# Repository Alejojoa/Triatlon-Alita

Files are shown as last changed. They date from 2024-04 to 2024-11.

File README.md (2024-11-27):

# Robot Triatlon - "ALITA" - SPACE ANGELS ROBOTICS
AlitaV2_photo

### Robot de competición desarrollado en el año 2024 por "Space Angels Robotics", con el objetivo de participar de los Juegos Bonaerenses del correspondiente año en la categoría de "Triatlón Robótico".
Campéon Regional en la categoría de "Triatlón Robótico" en la Universidad de Quilmes el (22 Ago).
Participación en los Juegos Bonaerenses 2024 (28 Oct. - 2 Nov.)

Llevado a cabo por alumnos de 6to año de la Técnica n°5 "2 de Abril" en la carrera de Electrónica.
Alita es un robot diseñado para fines plenamente educativos, contado con múltiples versiones, con el objetivo de superarse a si misma en cada una de sus etapas.

Todo el proyecto ha sido realizado en Vistual Studio Code con la extensión de PlarformIO en lenguaje C++ Orientado a Objetos.
Diseño de PCBs realizado en KiCad 8.0
Diseño de Hardware3D en Fusion 360

Participantes: Guerra Alejo Joaqín
               Lazzatti Lucas
               Regidor Jeremías
               Romano Iván
               Rossi Mamberti Valentina Jenifer

Director Técnico: Prof. Barzola Maximiliano Andrés

 Este robót cuenta con diferentes categorías, de las cuales cada una tendrá su rama individual con su última versión vigente.

 ## despeja_area
 Rama dedicada a la programación final (Alita V3) en la categoría de "Despeja Area" (Autonomo). Su objetivo será el de quitar de la pista una serie de cubos de la forma más rápida y eficiente posible, sin salir de la pista. 

   -.vscode
        Archivos generados por el IDE Visual Studio Code y la extensión de PlatformIO.
        
   -fimware
        Código actual individual de despeja_area.

 ## sprinter
 Rama dedicada a la programación final (Alita V3) en la categoría de "Velocista" (Autonomo). Su objetivo será el de completar una pista en su totalidad de la forma más rápida posible, pudiendo de igual forma incluir obstáculos o no.

   -.vscode
        Archivos generados por el IDE Visual Studio Code y la extensión de PlatformIO.
        
   -fimware
        Código actual individual de sprinter.

 ## sumo
 Rama dedicada a la programación final (Alita V3) en la categoría de "Sumo RC" (Radio Controlado). Su objertivo será el de quitar del tatami al rival, siendo un operario el encargado de manejar el robot. 

   -.vscode
        Archivos generados por el IDE Visual Studio Code y la extensión de PlatformIO.

   -fimware
        Código actual indiviual de sumo.

 ## menu
 Alita, en todas sus versiónes, incluye un menu comandado por pulsadores incluidos en el lateral izquierdo de robot para mayor comodidad del usuario. En esta rama encontrará la programación dedicada al manejo de esta interfaz. 

  -.vscode
       Archivos generados por el IDE Visual Studio Code y la extensión de PlatformIO.

  -fimware
       Programación de la interfaz de menú.

 ## main
 Esta es la rama principal del repositorio. En ella se encontrará la union de todas las ramas en una sola junto al hardware de Alita.

   -.vscode
        Archivos generados por el IDE Vistual Studio Code y la extensión de PlatformIO.

   -fimware
        Unión de las ramas individuales en una sola para mayor comodidad, dandole así a la interfaz del menu.

   -hardware
        PCBs empleadas en el robot, tanto como principales como drivers y multiplexores.

   -hardware 3D
        Diseños 3D de las diferentes versiones de Alita.

 ## stage
 Rama de pruebas de uniones previas a la rama main.

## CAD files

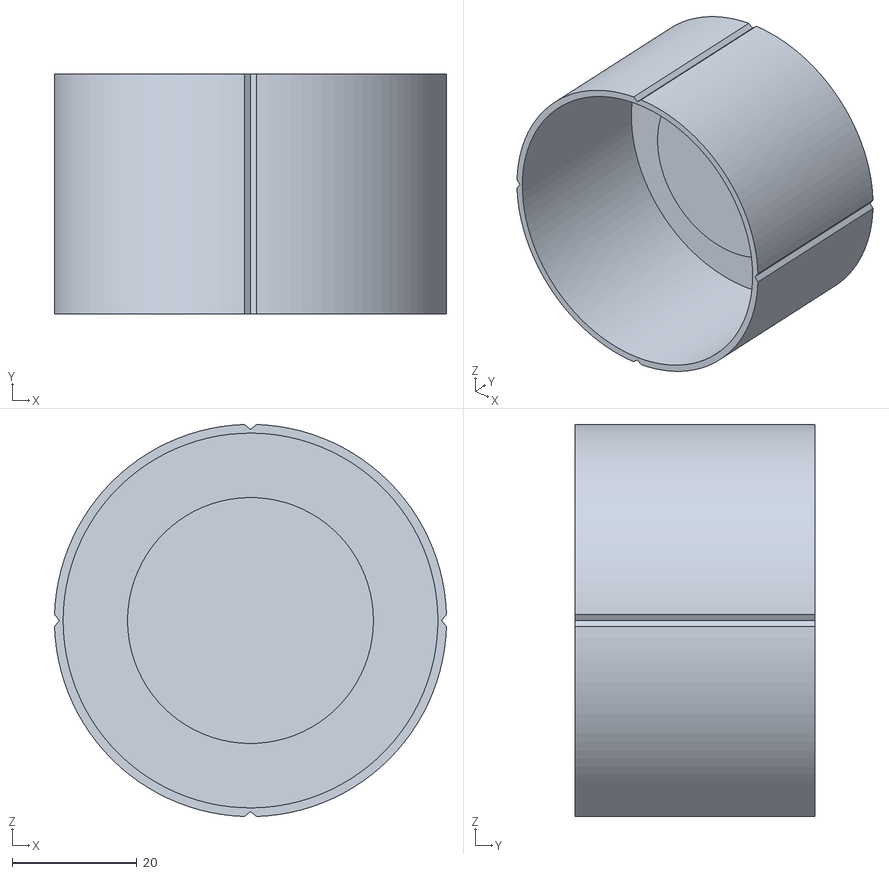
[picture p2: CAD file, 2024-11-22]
Hardware 3D/AlitaV3/RuedaTitanMolde60MM.stl
63.0 x 38.5 x 63.0

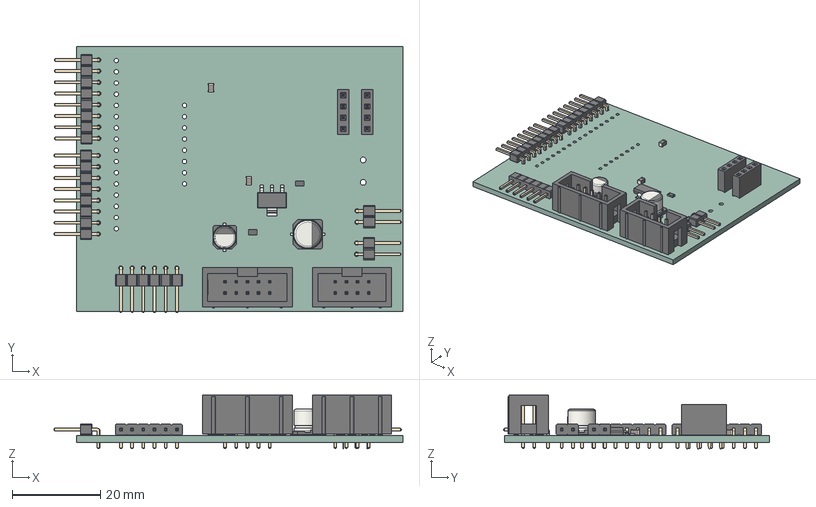
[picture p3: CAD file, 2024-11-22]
Hardware/PCBTriatlonNueva/PCBTriatlonNueva.step
79.1 x 60.2 x 12.2 mm
IDC_Header_2x05_P254mm_Vertical
CP_Elec_63x59
CP_Elec_5x45
SOT_223
R_0805_2012Metric x 2
PinSocket_1x04_P254mm_Vertical x 2
PinHeader_1x08_P254mm_Horizontal x 2
PinHeader_1x06_P254mm_Horizontal
C_0805_2012Metric x 2
PinHeader_1x02_P254mm_Horizontal x 2
IDC_Header_2x04_P254mm_Vertical
PCBTriatlonNueva_PCB

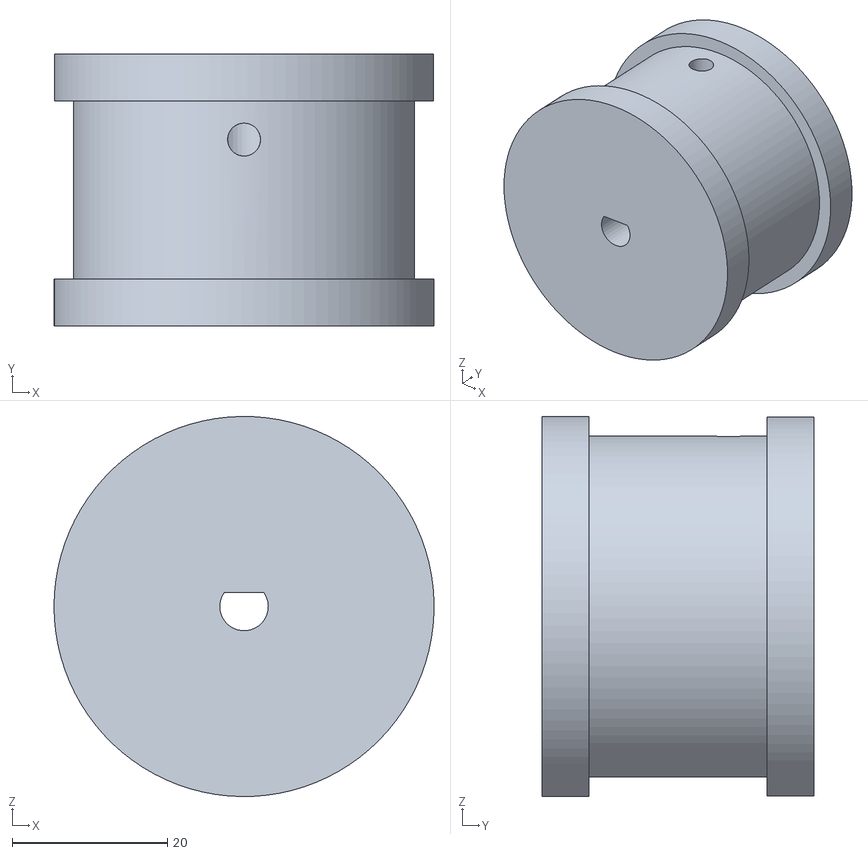
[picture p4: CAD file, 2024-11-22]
Hardware 3D/AlitaV3/Rueda60MM Mod.stl
49.0 x 35.0 x 49.0

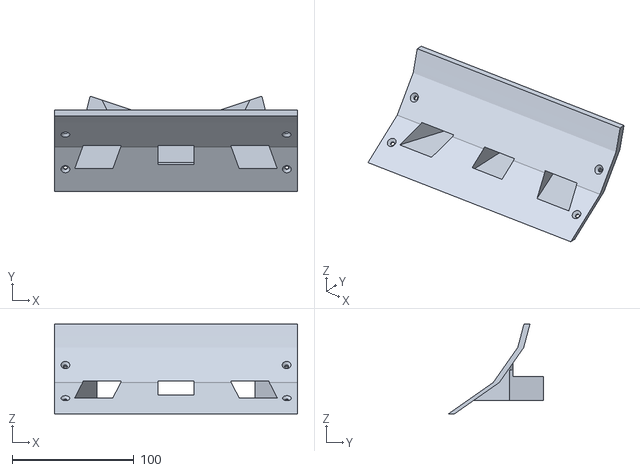
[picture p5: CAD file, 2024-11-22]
Hardware 3D/AlitaV3/Frente del chasis.stl
200.0 x 78.3 x 73.9

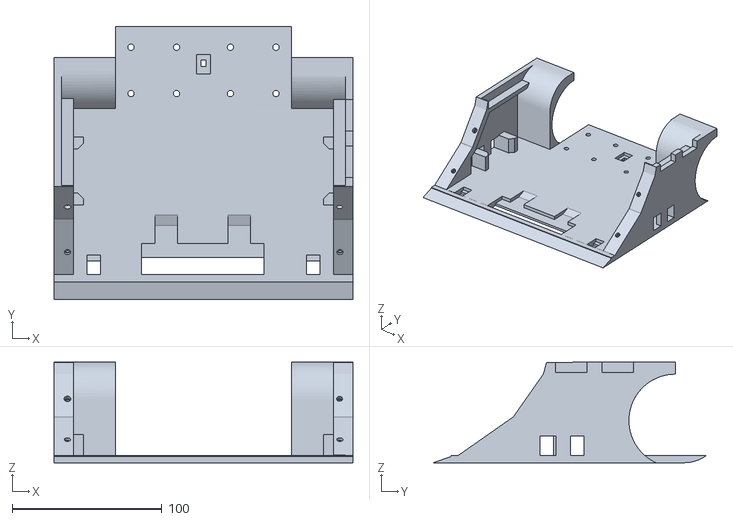
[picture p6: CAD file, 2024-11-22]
Hardware 3D/AlitaV3/ChasisV3.stl
200.0 x 182.9 x 67.3

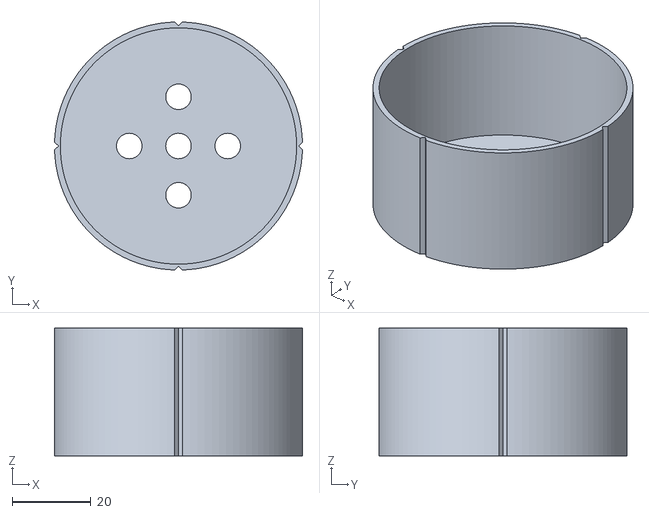
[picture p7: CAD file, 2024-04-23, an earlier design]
Hardware 3D/AlitaV1/MoldeRueda60MM.stl
63.0 x 63.0 x 32.5

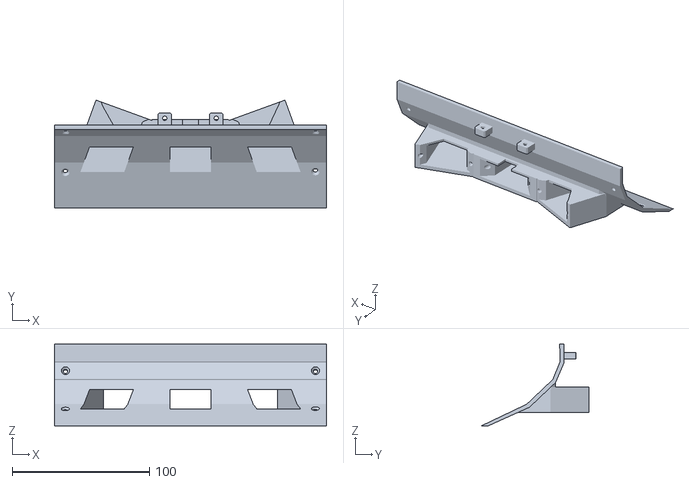
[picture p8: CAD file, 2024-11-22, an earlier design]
Hardware 3D/AlitaV2.1/FrenteAlitaV2.stl
198.0 x 78.5 x 59.7

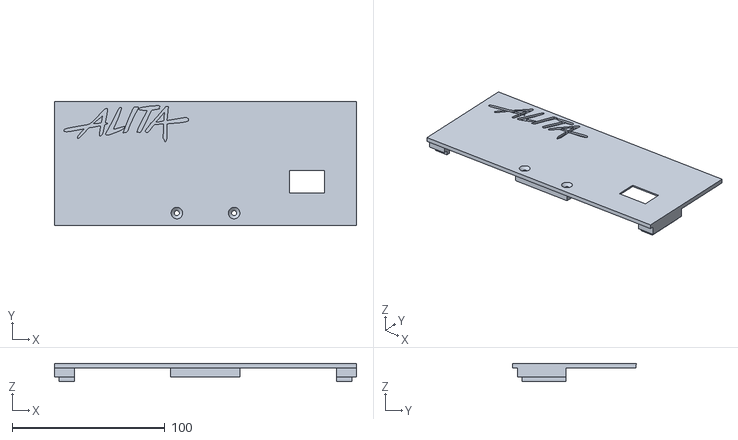
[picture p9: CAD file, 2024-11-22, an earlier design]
Hardware 3D/AlitaV2.1/Old/TapaAlitaV2.stl
198.0 x 81.0 x 12.0

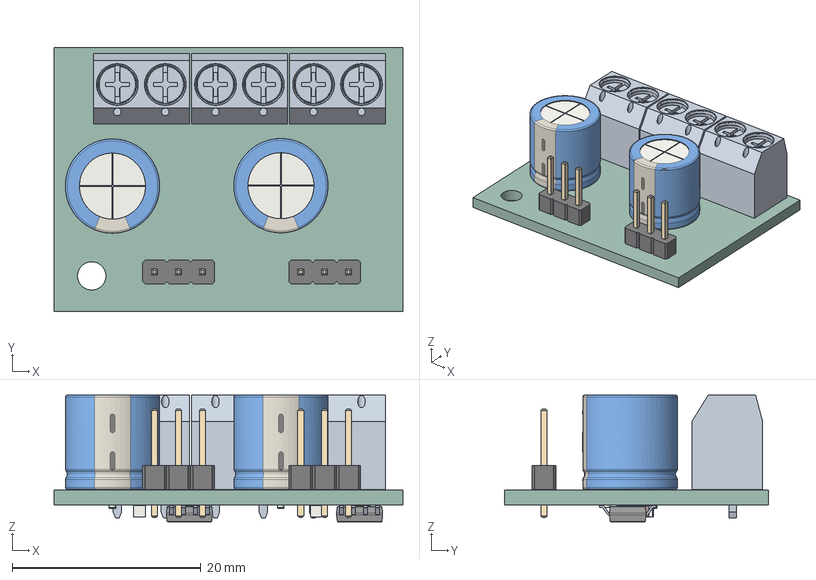
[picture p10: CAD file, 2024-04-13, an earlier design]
Hardware/old_DriverMotoresx2TB67H450FNG/DriverMotoresx2TB67H450FNG.step
37.0 x 28.0 x 13.5 mm
PinHeader_1x03_P254mm_Vertical x 2
ASSEMBLY x 5
CP_Radial_D100mm_P500mm x 2
C_0805_2012Metric x 2
DriverMotoresx2TB67H450FNG_PCB

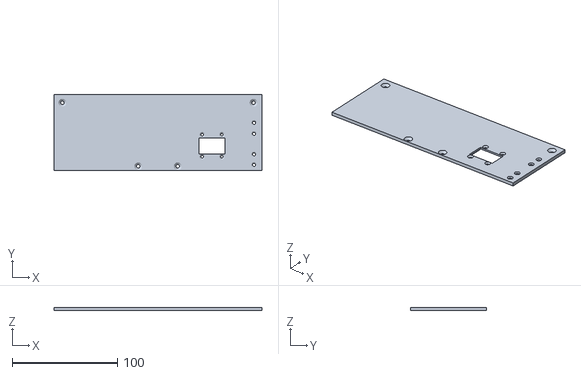
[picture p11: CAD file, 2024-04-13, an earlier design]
Hardware 3D/AlitaV1/Tapa robot.stl
198.0 x 72.6 x 3.00

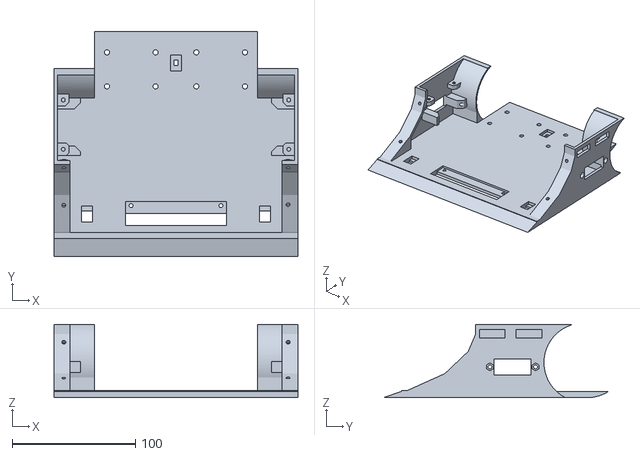
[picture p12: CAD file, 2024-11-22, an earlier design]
Hardware 3D/AlitaV2.1/Old/ChasisAlitaV2.stl
198.0 x 182.4 x 59.5

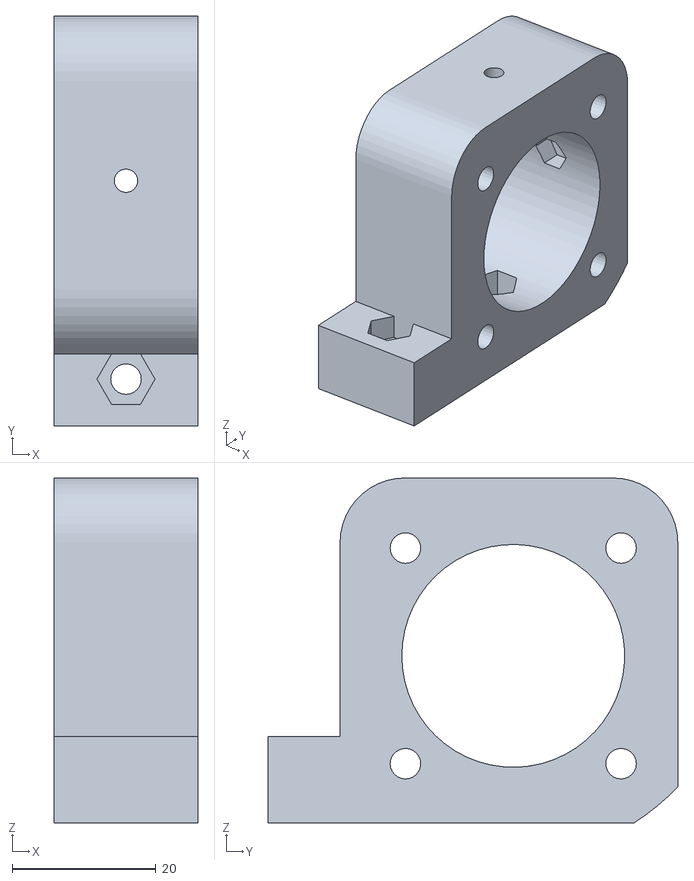
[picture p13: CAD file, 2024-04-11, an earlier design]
Hardware 3D/AlitaV1/SoporteIzquierdo.stl
20.0 x 57.0 x 48.0

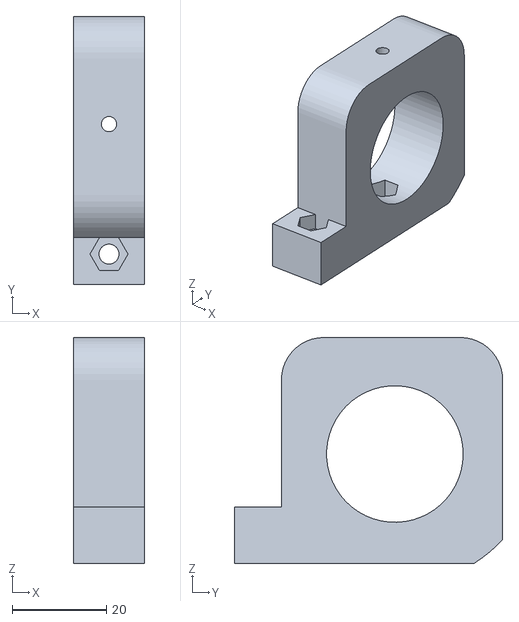
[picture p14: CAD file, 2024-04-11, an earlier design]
Hardware 3D/AlitaV1/SoporteCentral.stl
15.0 x 57.0 x 48.0

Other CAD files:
Hardware 3D/AlitaV2.1/Tapa PantallaOled1.3.stl
Hardware 3D/AlitaV1/SoporteDerecho.stl
Hardware 3D/AlitaV2.1/SoporteDerecho.stl
Hardware 3D/AlitaV1/Chasis principal.stl

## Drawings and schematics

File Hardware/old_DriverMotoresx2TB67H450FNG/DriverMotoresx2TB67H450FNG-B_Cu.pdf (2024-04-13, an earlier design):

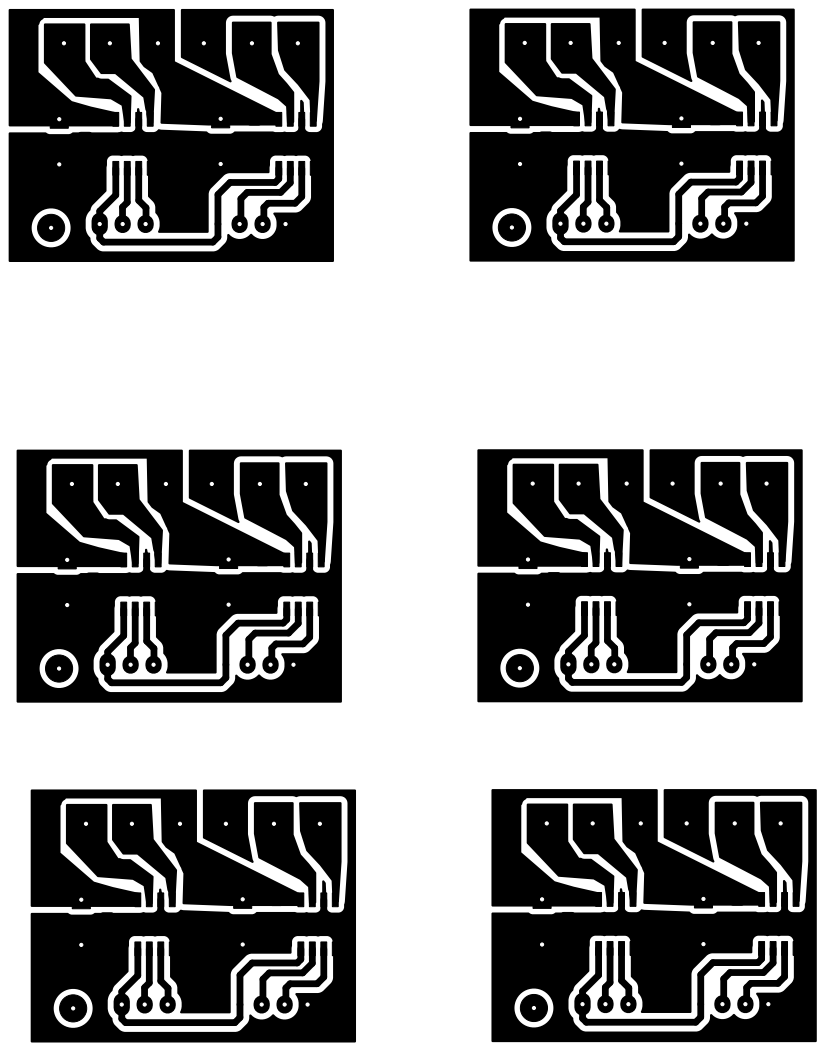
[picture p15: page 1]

Id: 1/1 Title: File: DriverMotoresx2TB67H450FNG.kicad_pcb Sheet:

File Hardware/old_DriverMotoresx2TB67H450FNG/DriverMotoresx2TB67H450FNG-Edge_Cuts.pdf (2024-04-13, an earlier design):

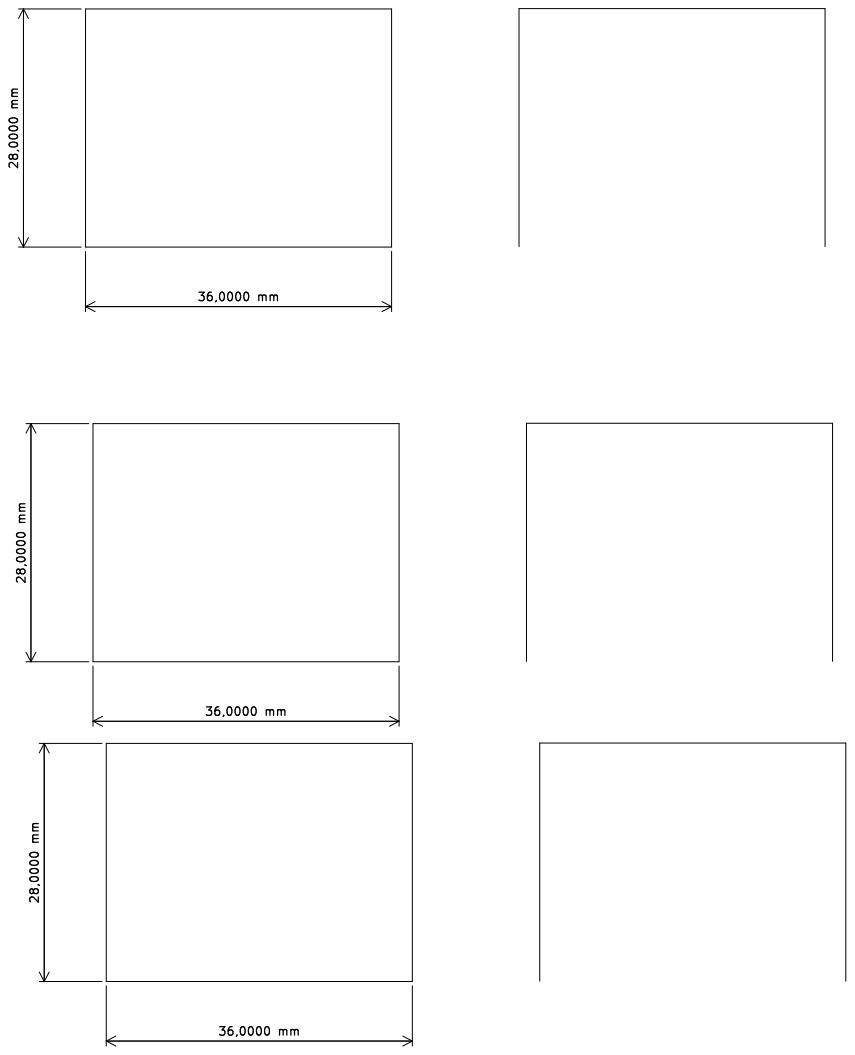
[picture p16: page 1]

Id: 1/1 Title: File: DriverMotoresx2TB67H450FNG.kicad_pcb Sheet: 28,0000 mm

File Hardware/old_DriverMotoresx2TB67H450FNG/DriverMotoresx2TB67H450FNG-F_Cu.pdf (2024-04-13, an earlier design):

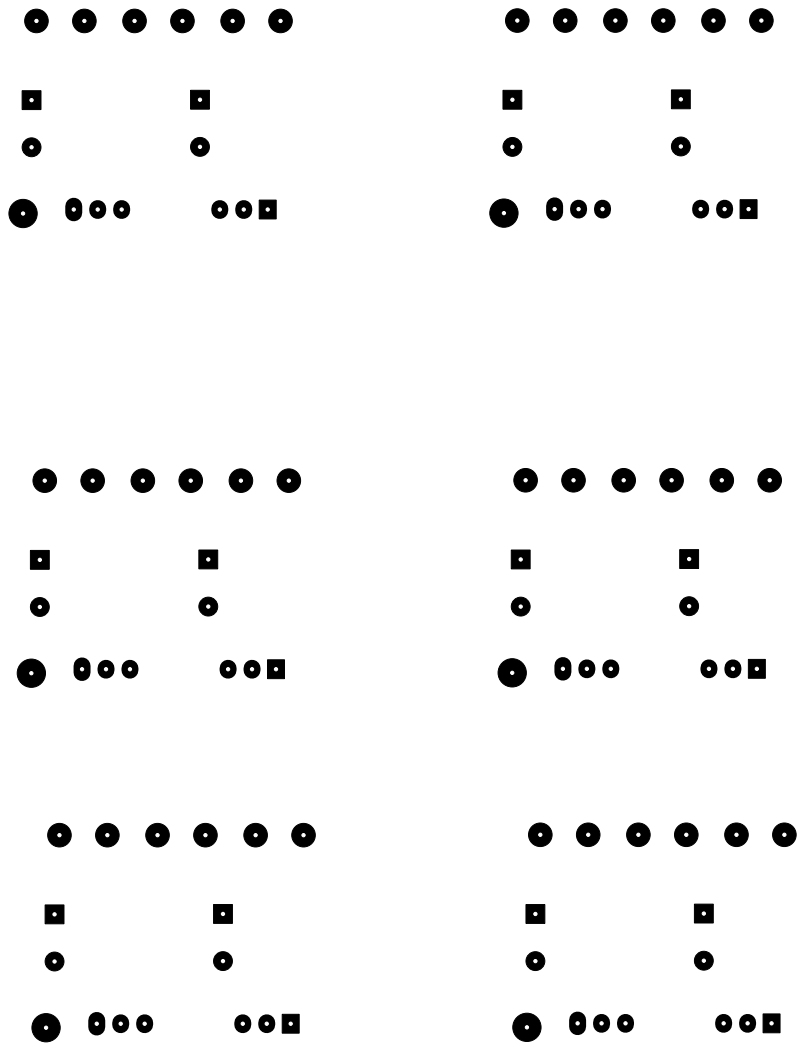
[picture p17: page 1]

Id: 1/1 Title: File: DriverMotoresx2TB67H450FNG.kicad_pcb Sheet:

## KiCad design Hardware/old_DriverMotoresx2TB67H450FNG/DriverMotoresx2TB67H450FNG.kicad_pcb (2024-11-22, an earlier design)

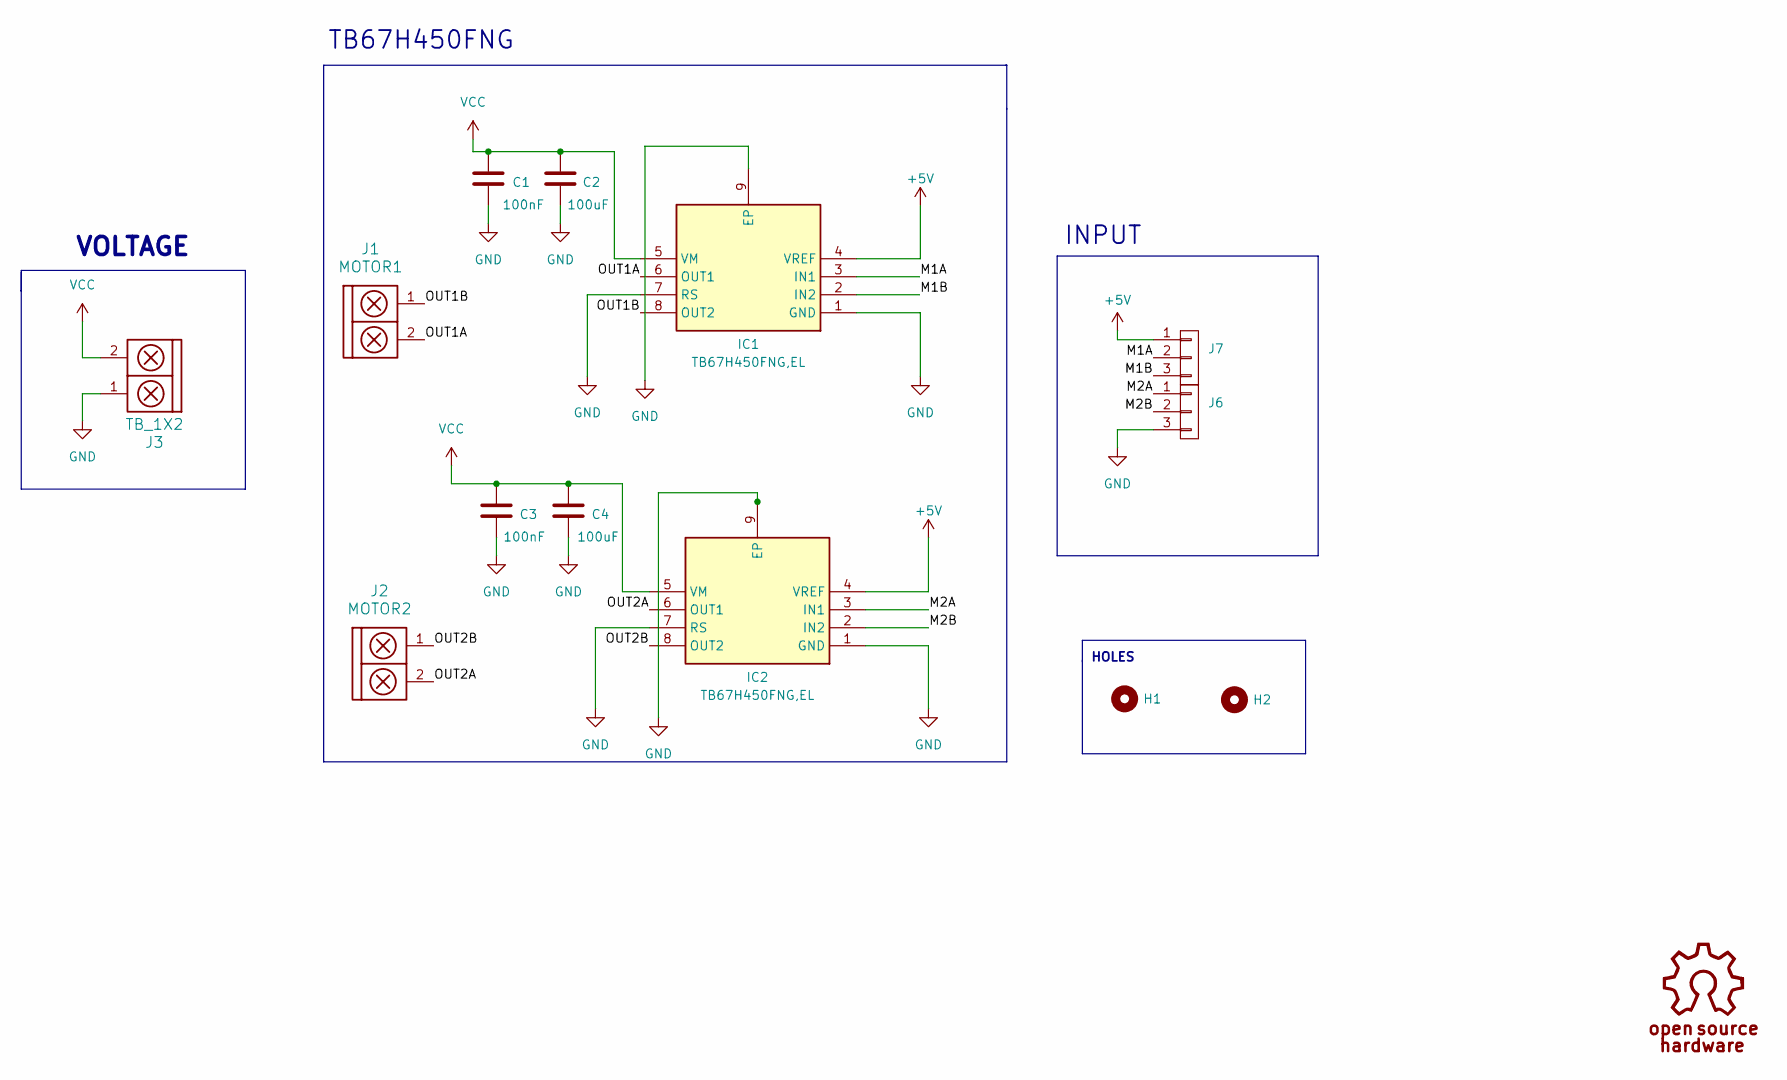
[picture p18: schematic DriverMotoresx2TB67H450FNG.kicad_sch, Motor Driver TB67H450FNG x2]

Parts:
C1, C3: 100nF; C_0805_2012Metric_Pad1.18x1.45mm_HandSolder
C2, C4: 100uF; CP_Radial_D10.0mm_P5.00mm
H1, H2: Mounting_Hole; hole_3mm
IC1, IC2: TB67H450FNG,EL; SOIC127P600X170-9N; Mouser Part Number 757-TB67H450FNGEL
J1: MOTOR1; BORNERA2_AZUL
J2: MOTOR2; BORNERA2_AZUL
J3: TB_1X2; BORNERA2_AZUL
J6, J7: Conn_01X03; PinHeader_1x03_P2.54mm_Vertical

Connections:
+5V: IC1.4 (VREF), IC2.4 (VREF), J7.1
/M1A: IC1.3 (IN1), J7.2
/M1B: IC1.2 (IN2), J7.3
/M2A: IC2.3 (IN1), J6.1
/M2B: IC2.2 (IN2), J6.2
/OUT1A: IC1.6 (OUT1), J1.2
/OUT1B: IC1.8 (OUT2), J1.1
/OUT2A: IC2.6 (OUT1), J2.2
/OUT2B: IC2.8 (OUT2), J2.1
GND: C1.2, C2.2, C3.2, C4.2, IC1.1 (GND), IC1.7 (RS), IC1.9 (EP), IC2.1 (GND), IC2.7 (RS), IC2.9 (EP), J3.1, J6.3
VCC: C1.1, C2.1, C3.1, C4.1, IC1.5 (VM), IC2.5 (VM), J3.2

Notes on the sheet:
HOLES
INPUT
TB67H450FNG
VOLTAGE

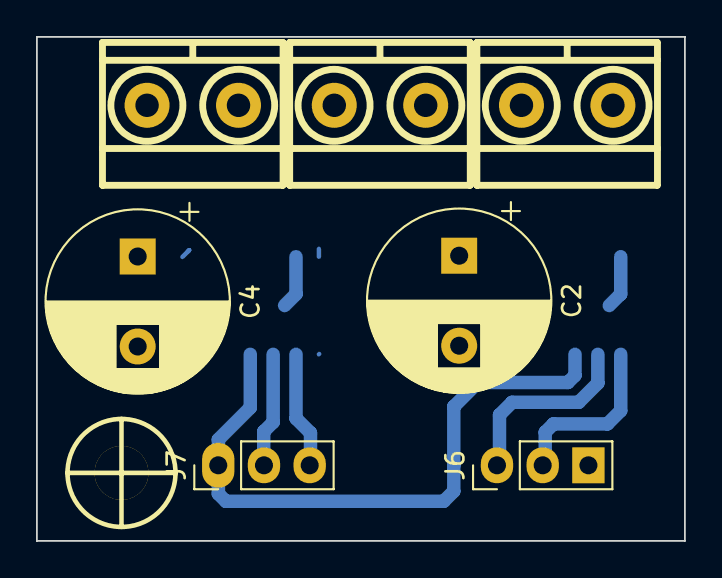
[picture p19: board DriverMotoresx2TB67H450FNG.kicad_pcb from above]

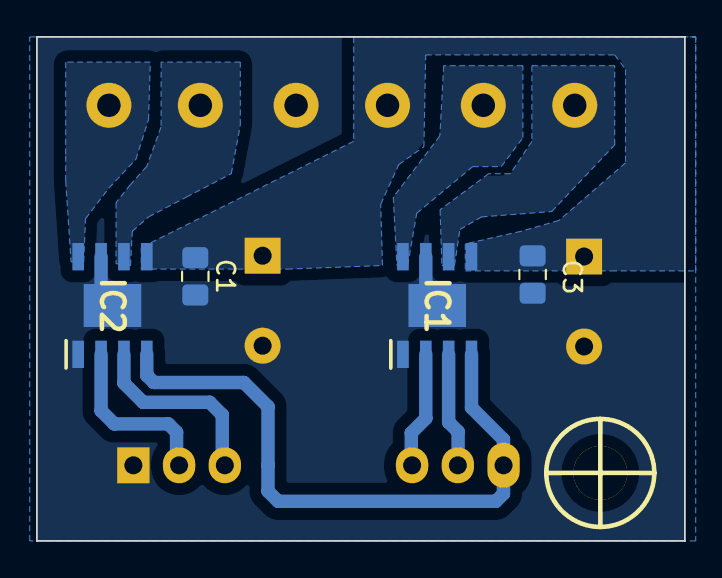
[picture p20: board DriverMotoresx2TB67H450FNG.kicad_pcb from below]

Board: 2 copper layers, 36.0 x 28.0 mm, 12 parts (4 on the bottom side), 11 nets.

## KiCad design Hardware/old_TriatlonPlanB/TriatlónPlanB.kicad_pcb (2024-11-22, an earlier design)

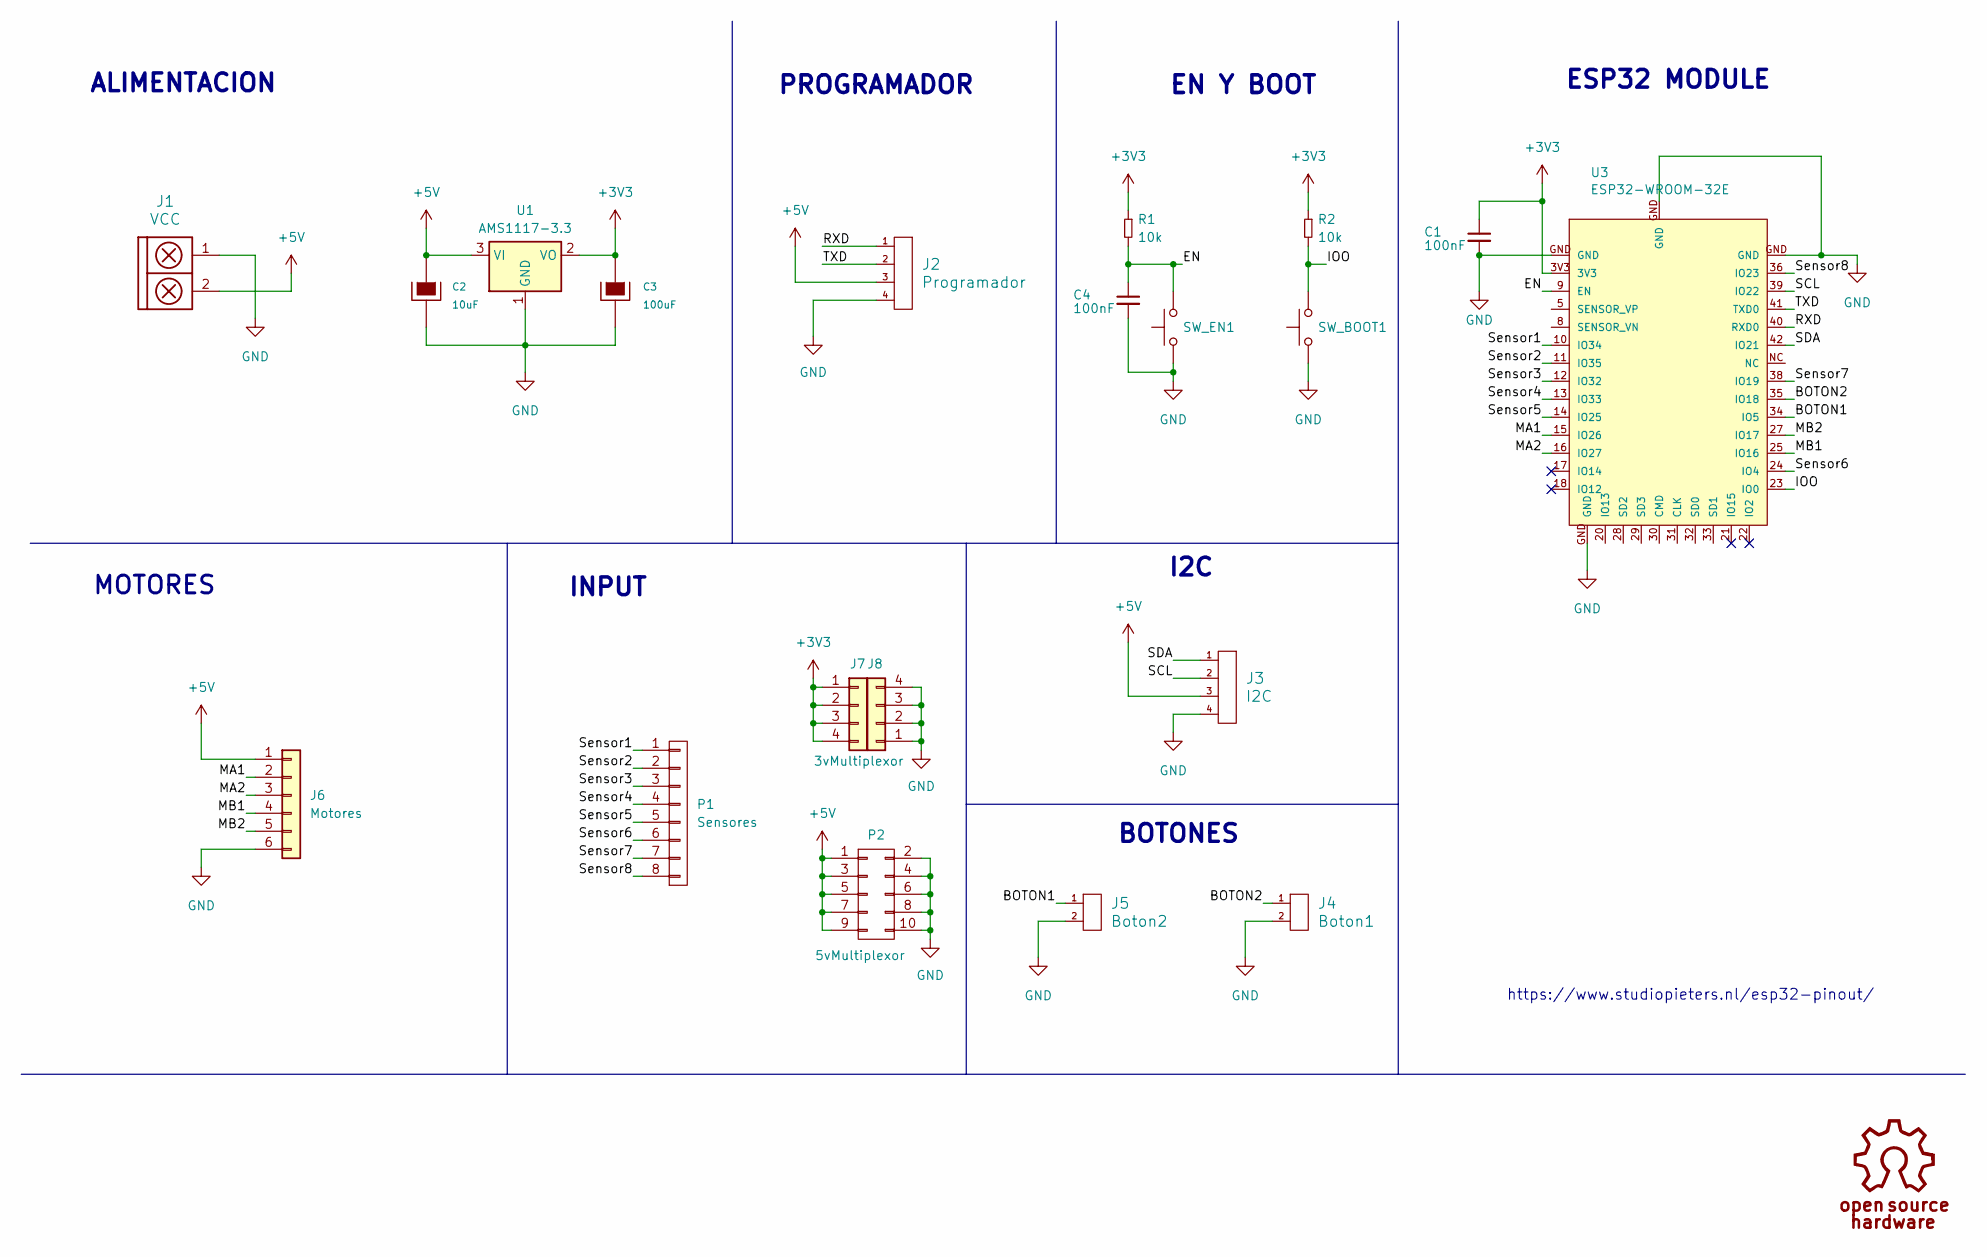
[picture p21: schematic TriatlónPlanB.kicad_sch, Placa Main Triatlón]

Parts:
C1, C4: 100nF; C_0805
C2: 10uF; CP_Elec_5x4.5
C3: 100uF; CP_Elec_6.3x5.9
J1: VCC; BORNERA2_AZUL
J2: Programador; PinSocket_1x04_P2.54mm_Vertical
J3: I2C; PinSocket_1x04_P2.54mm_Vertical
J4: Boton1; PinHeader_1x02_P2.54mm_Vertical
J5: Boton2; PinHeader_1x02_P2.54mm_Vertical
J6: Motores; Pin_Header_6
J7, J8: 3vMultiplexor; pin_strip_4
P1: Sensores; PinSocket_1x08_P2.54mm_Vertical
P2: 5vMultiplexor; Pin_Header_02x05
R1, R2: 10k; R_0805_2012Metric
SW_BOOT1: SW_Push; Pulsador_SMD_2_ALTO
SW_EN1: SW_Push; Pulsador_SMD_2_ALTO
U1: AMS1117-3.3; SOT-223-3_TabPin2
U3: ESP32-WROOM-32E

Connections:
+3V3: C1.1, C3.1, J7.1, J7.2, J7.3, J7.4, R1.1, R2.1, U1.2 (VO), U3.3V3
+5V: C2.1, J1.2, J2.3, J3.3, J6.1, P2.1, P2.3, P2.5, P2.7, P2.9, U1.3 (VI)
/BOTON1: J5.1, U3.34 (IO5)
/BOTON2: J4.1, U3.35 (IO18)
/EN: C4.1, R1.2, SW_EN1.2, U3.9 (EN)
/IOO: R2.2, SW_BOOT1.2, U3.23 (IO0)
/MA1: J6.2, U3.15 (IO26)
/MA2: J6.3, U3.16 (IO27)
/MB1: J6.4, U3.25 (IO16)
/MB2: J6.5, U3.27 (IO17)
/RXD: J2.1, U3.40 (RXD0)
/SCL: J3.2, U3.39 (IO22)
/SDA: J3.1, U3.42 (IO21)
/Sensor1: P1.1, U3.10 (IO34)
/Sensor2: P1.2, U3.11 (IO35)
/Sensor3: P1.3, U3.12 (IO32)
/Sensor4: P1.4, U3.13 (IO33)
/Sensor5: P1.5, U3.14 (IO25)
/Sensor7: P1.7, U3.38 (IO19)
/Sensor8: P1.8, U3.36 (IO23)
/TXD: J2.2, U3.41 (TXD0)
GND: C1.2, C2.2, C3.2, C4.2, J1.1, J2.4, J3.4, J4.2, J5.2, J6.6, J8.1, J8.2, J8.3, J8.4, P2.2, P2.4, P2.6, P2.8, P2.10, SW_BOOT1.1, SW_EN1.1, U1.1 (GND), U3.GND

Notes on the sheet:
INPUT
BOTONES
ALIMENTACION
I2C
EN Y BOOT
ESP32 MODULE
PROGRAMADOR
https://www.studiopieters.nl/esp32-pinout/
MOTORES

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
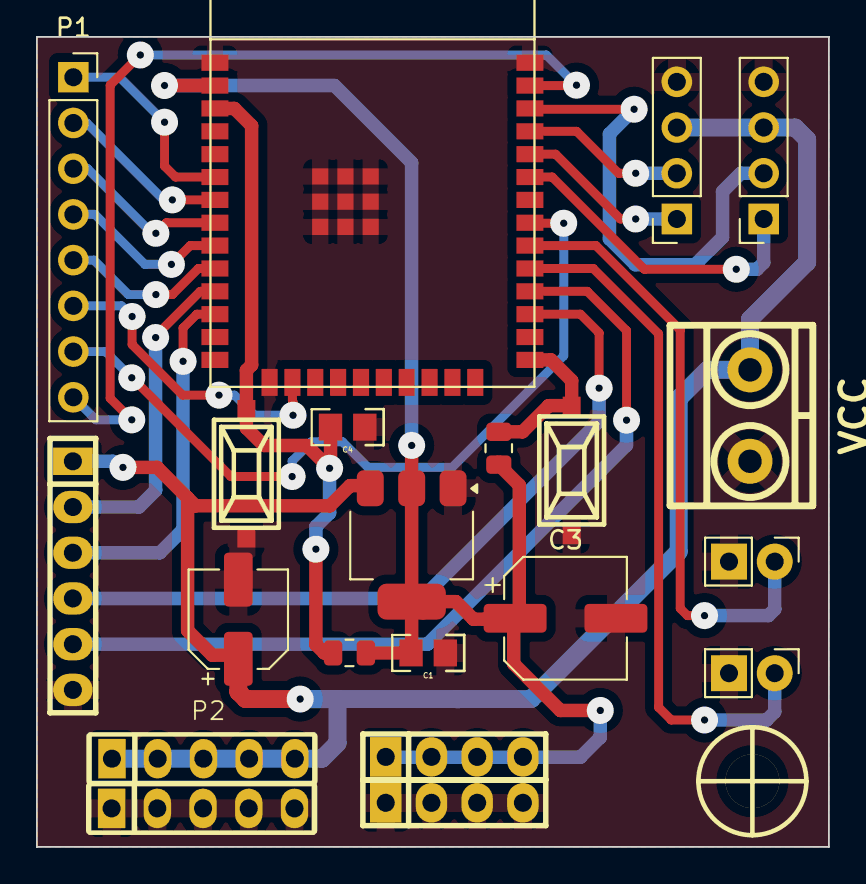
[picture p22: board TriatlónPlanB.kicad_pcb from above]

Board: 2 copper layers, 44.0 x 45.0 mm, 21 parts (0 on the bottom side), 23 nets.

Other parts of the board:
hole_3mm: VAL**; hole_3mm

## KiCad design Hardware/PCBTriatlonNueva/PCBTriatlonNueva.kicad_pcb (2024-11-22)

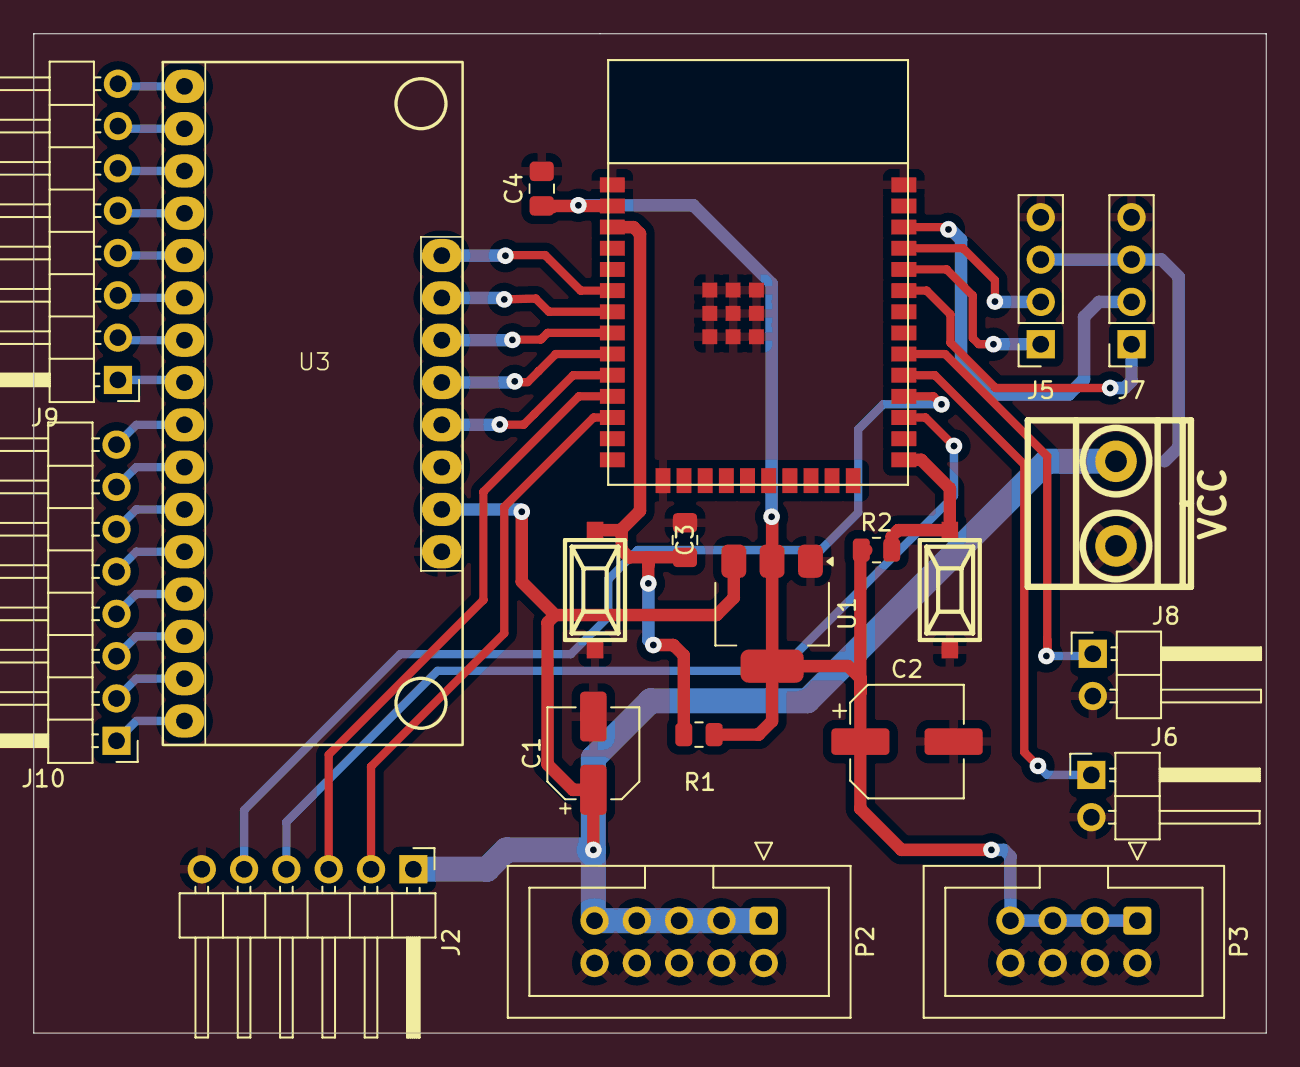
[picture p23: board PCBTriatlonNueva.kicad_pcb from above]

Board: 2 copper layers, 74.0 x 60.0 mm, 21 parts (0 on the bottom side), 36 nets.

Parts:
C1: 10uF; CP_Elec_5x4.5
C2: 100uF; CP_Elec_6.3x5.9
C3, C4: 100nF; C_0805_2012Metric_Pad1.18x1.45mm_HandSolder
J1: VCC; BORNERA2
J2: Motores; PinHeader_1x06_P2.54mm_Horizontal
J5: Programador; PinSocket_1x04_P2.54mm_Vertical
J6: Boton2; PinHeader_1x02_P2.54mm_Horizontal
J7: I2C; PinSocket_1x04_P2.54mm_Vertical
J8: Boton1; PinHeader_1x02_P2.54mm_Horizontal
J9: MUX_header1; PinHeader_1x08_P2.54mm_Horizontal
J10: MUX_header2; PinHeader_1x08_P2.54mm_Horizontal
P2: 5vMultiplexor; IDC-Header_2x05_P2.54mm_Vertical
P3: 5vMultiplexor; IDC-Header_2x04_P2.54mm_Vertical
R1, R2: 10k; R_0805_2012Metric
SW_BOOT1: SW_Push; Pulsador_SMD_2_ALTO
SW_EN1: SW_Push; Pulsador_SMD_2_ALTO
U1: AMS1117-3.3; SOT-223-3_TabPin2
U2: ESP32-WROOM-32E
U3: MUX 4067; HP4067_module

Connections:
+3V3: C2.1, C4.1, P3.1, P3.3, P3.5, P3.7, R1.1, R2.1, U1.2 (VO), U2.3V3
+5V: C1.1, J1.2, J2.1, J5.3, J7.3, P2.1, P2.3, P2.5, P2.7, P2.9, U1.3 (VI), U3.23 (VCC)
/BOTON1: J6.1, U2.34 (IO5)
/BOTON2: J8.1, U2.35 (IO18)
/EN: C3.1, R1.2, SW_EN1.2, U2.9 (EN)
/IOO: R2.2, SW_BOOT1.2, U2.23 (IO0)
/MA1: J2.3, U2.15 (IO26)
/MA2: J2.2, U2.16 (IO27)
/MB1: J2.4, U2.25 (IO16)
/MB2: J2.5, U2.27 (IO17)
/MULTIPLEXOR1: U2.14 (IO25), U3.21 (S0)
/MULTIPLEXOR2: U2.13 (IO33), U3.20 (S1)
/MULTIPLEXOR3: U2.12 (IO32), U3.19 (S2)
/MULTIPLEXOR4: U2.11 (IO35), U3.18 (S3)
/MULTIPLEXOR5: U2.10 (IO34), U3.17 (SIG)
/RXD: J5.1, U2.40 (RXD0)
/SCL: J7.2, U2.39 (IO22)
/SDA: J7.1, U2.42 (IO21)
/TXD: J5.2, U2.41 (TXD0)
GND: C1.2, C2.2, C3.2, C4.2, J1.1, J2.6, J5.4, J6.2, J7.4, J8.2, P2.2, P2.4, P2.6, P2.8, P2.10, P3.2, P3.4, P3.6, P3.8, SW_BOOT1.1, SW_EN1.1, U1.1 (GND), U2.GND, U3.24 (GND)
unnamed: J9.1, U3.8 (C8)
unnamed: J9.2, U3.7 (C9)
unnamed: J9.3, U3.6 (C10)
unnamed: J9.4, U3.5 (C11)
unnamed: J9.5, U3.4 (C12)
unnamed: J9.6, U3.3 (C13)
unnamed: J9.7, U3.2 (C14)
unnamed: J9.8, U3.1 (C15)
unnamed: J10.1, U3.16 (C0)
unnamed: J10.2, U3.15 (C1)
unnamed: J10.3, U3.14 (C2)
unnamed: J10.4, U3.13 (C3)
unnamed: J10.5, U3.12 (C4)
unnamed: J10.6, U3.11 (C5)
unnamed: J10.7, U3.10 (C6)
unnamed: J10.8, U3.9 (C7)

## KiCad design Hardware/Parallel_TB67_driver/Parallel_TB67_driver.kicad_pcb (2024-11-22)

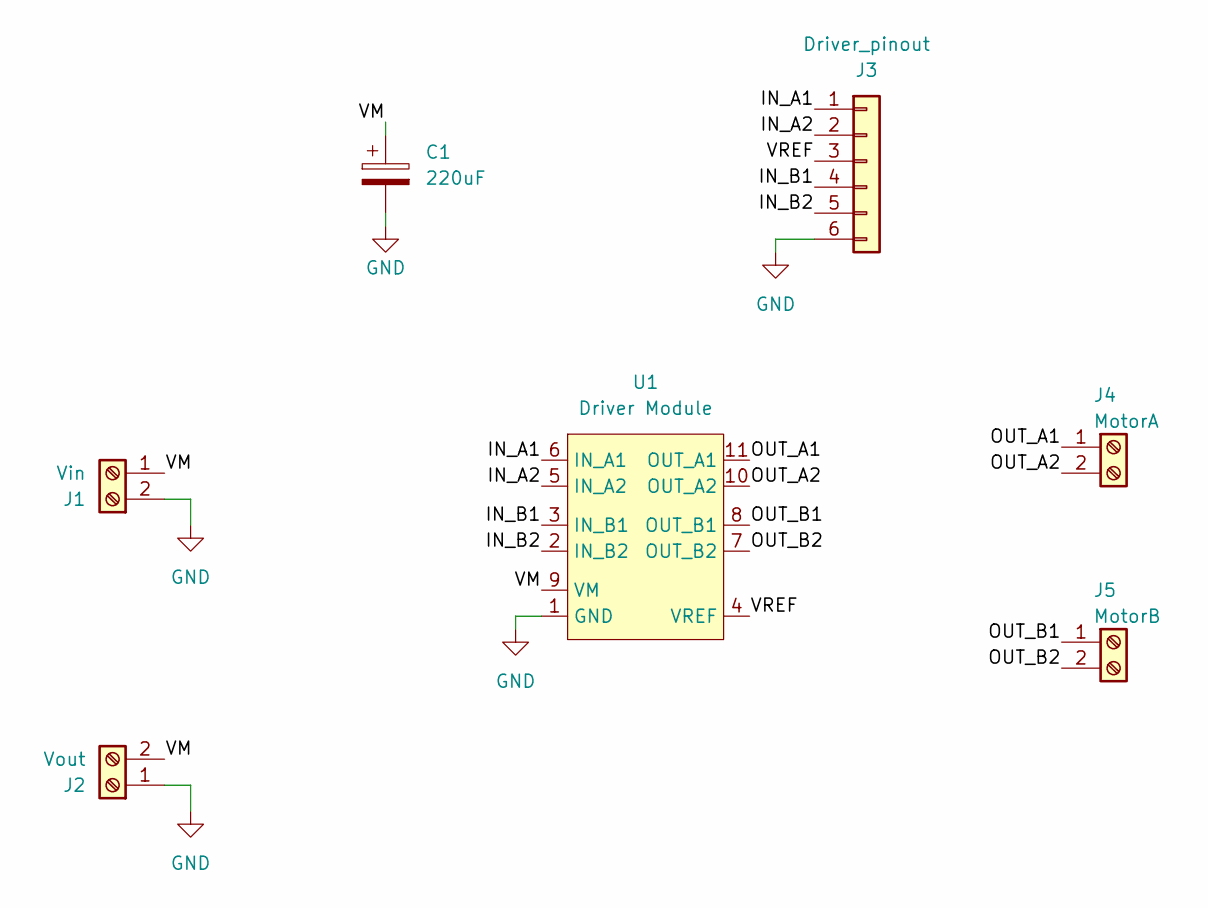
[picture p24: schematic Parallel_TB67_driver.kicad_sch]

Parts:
C1: 220uF; CP_Radial_D10.0mm_P3.50mm
J1: Vin; BORNERA2_AZUL
J2: Vout; BORNERA2_AZUL
J3: Driver_pinout; Molex_KK-254_AE-6410-06A_1x06_P2.54mm_Vertical
J4: MotorA; BORNERA2_AZUL
J5: MotorB; BORNERA2_AZUL
U1: Driver Module; Dual-Driver-Module

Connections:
/IN_A1: J3.1, U1.6 (IN_A1)
/IN_A2: J3.2, U1.5 (IN_A2)
/IN_B1: J3.4, U1.3 (IN_B1)
/IN_B2: J3.5, U1.2 (IN_B2)
/OUT_A1: J4.1, U1.11 (OUT_A1)
/OUT_A2: J4.2, U1.10 (OUT_A2)
/OUT_B1: J5.1, U1.8 (OUT_B1)
/OUT_B2: J5.2, U1.7 (OUT_B2)
/VM: C1.1, J1.1 (Pin_2), J2.2, U1.9 (VM)
/VREF: J3.3, U1.4 (VREF)
GND: C1.2, J1.2 (Pin_1), J2.1, J3.6, U1.1 (GND)

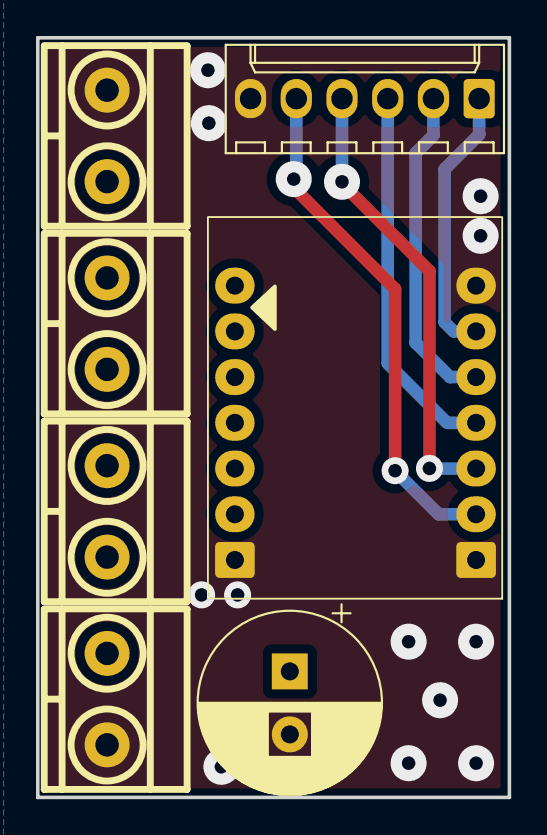
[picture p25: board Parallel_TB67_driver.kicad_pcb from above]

Board: 2 copper layers, 26.2 x 42.2 mm, 7 parts (0 on the bottom side), 11 nets.

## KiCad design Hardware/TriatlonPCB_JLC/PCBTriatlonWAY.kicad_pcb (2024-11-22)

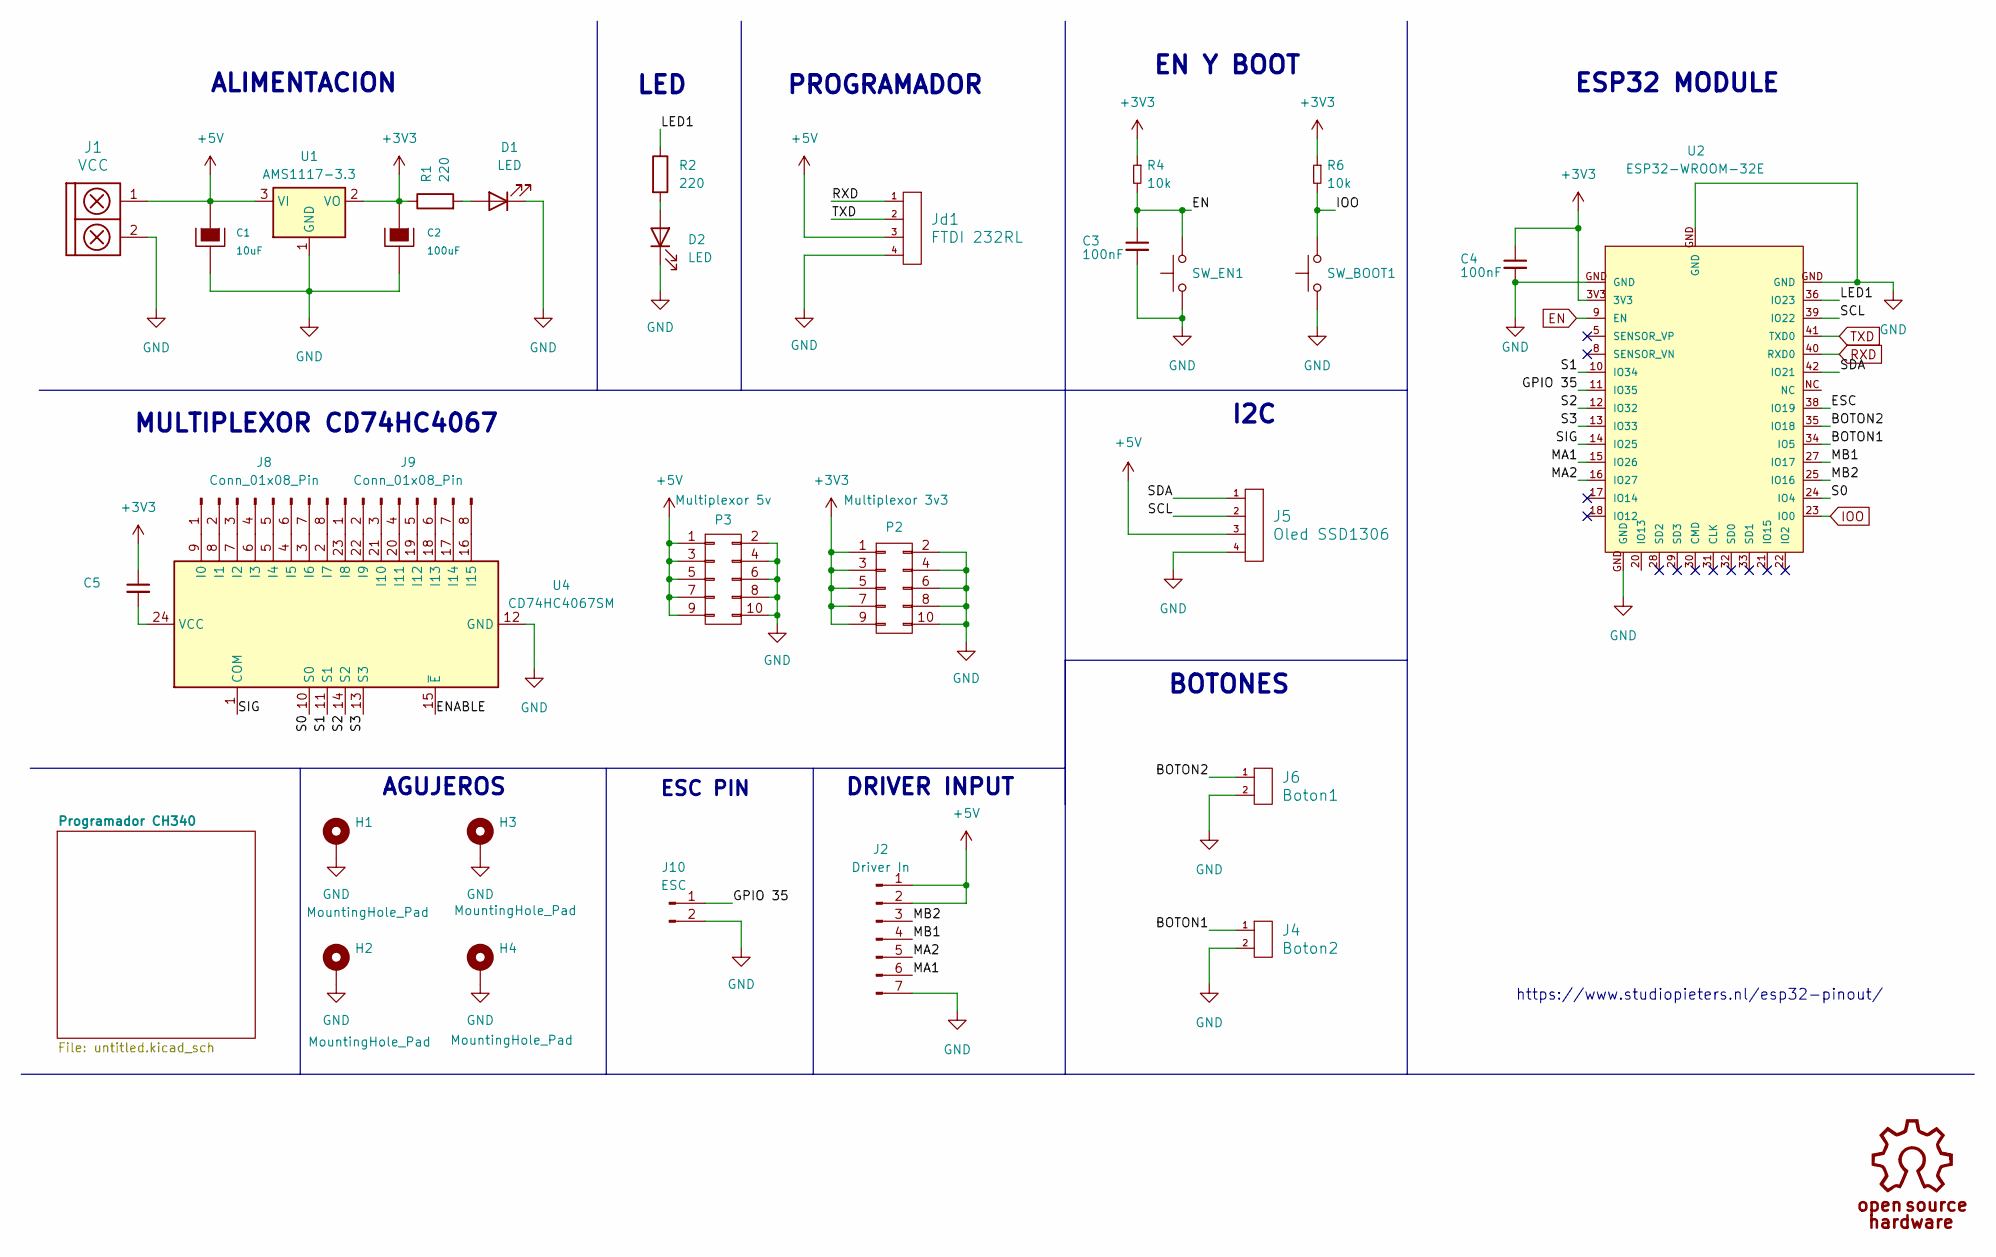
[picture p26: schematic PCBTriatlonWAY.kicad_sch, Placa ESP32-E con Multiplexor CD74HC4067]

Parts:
C1: 10uF; CP_Elec_5x4.5
C2: 100uF; CP_Elec_6.3x5.9
C3, C4: 100nF; C_0805_2012Metric_Pad1.18x1.45mm_HandSolder
C5: C_0805_2012Metric_Pad1.18x1.45mm_HandSolder
D1, D2: LED; LED_0805_2012Metric_Pad1.15x1.40mm_HandSolder
H1, H2, H3, H4: MountingHole_Pad; MountingHole_3mm_Pad_Via
J1: VCC; BORNERA2_DUO
J2: Driver In; PinHeader_1x07_P2.54mm_Horizontal
J4: Boton2; PinHeader_1x02_P2.54mm_Horizontal
J5: Oled SSD1306; Molex_KK-254_AE-6410-04A_1x04_P2.54mm_Vertical
J6: Boton1; PinHeader_1x02_P2.54mm_Horizontal
J8, J9: Conn_01x08_Pin; PinHeader_1x08_P2.54mm_Horizontal
J10: ESC; Molex_KK-254_AE-6410-02A_1x02_P2.54mm_Vertical
Jd1: FTDI 232RL; PinHeader_1x04_P2.54mm_Vertical
P2: Multiplexor 3v3; IDC-Header_2x05_P2.54mm_Vertical
P3: Multiplexor 5v; IDC-Header_2x05_P2.54mm_Vertical
R1, R2: 220; R_0805_2012Metric_Pad1.20x1.40mm_HandSolder
R4, R6: 10k; R_0805_2012Metric_Pad1.20x1.40mm_HandSolder
SW_BOOT1: SW_Push; Pulsador_SMD_2_BAJO
SW_EN1: SW_Push; Pulsador_SMD_2_BAJO
U1: AMS1117-3.3; SOT-223-3_TabPin2
U2: ESP32-WROOM-32E
U4: CD74HC4067SM; SSOP-24_5.3x8.2mm_P0.65mm

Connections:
+3V3: C2.1, C4.1, C5.1, P2.1, P2.3, P2.5, P2.7, P2.9, R1.1, R4.1, R6.1, U1.2 (VO), U2.3V3
+5V: C1.1, J1.1, J2.1, J2.2, J5.3, Jd1.3, P3.1, P3.3, P3.5, P3.7, P3.9, U1.3 (VI); also elsewhere on the board
/BOTON1: J4.1, U2.34 (IO5)
/BOTON2: J6.1, U2.35 (IO18)
/ENABLE: U4.15 (~E)
/ESC: U2.38 (IO19)
/GPIO 35: J10.1, U2.11 (IO35)
/LED1: R2.1, U2.36 (IO23)
/MA1: J2.6, U2.15 (IO26)
/MA2: J2.5, U2.16 (IO27)
/MB1: J2.4, U2.27 (IO17)
/MB2: J2.3, U2.25 (IO16)
/S0: U2.24 (IO4), U4.10 (S0)
/S1: U2.10 (IO34), U4.11 (S1)
/S2: U2.12 (IO32), U4.14 (S2)
/S3: U2.13 (IO33), U4.13 (S3)
/SCL: J5.2, U2.39 (IO22)
/SDA: J5.1, U2.42 (IO21)
/SIG: U2.14 (IO25), U4.1 (COM)
EN: C3.1, R4.2, SW_EN1.2, U2.9 (EN)
GND: C1.2, C2.2, C3.2, C4.2, D1.1 (K), D2.1 (K), H1.1, H2.1, H3.1, H4.1, J1.2, J2.7, J4.2, J5.4, J6.2, J10.2, Jd1.4, P2.2, P2.4, P2.6, P2.8, P2.10, P3.2, P3.4, P3.6, P3.8, P3.10, SW_BOOT1.1, SW_EN1.1, U1.1 (GND), U2.GND, U4.12 (GND); also elsewhere on the board
IOO: R6.2, SW_BOOT1.2, U2.23 (IO0)
unnamed: D1.2 (A), R1.2
unnamed: D2.2 (A), R2.2
unnamed: J8.1, U4.9 (I0)
unnamed: J8.2, U4.8 (I1)
unnamed: J8.3, U4.7 (I2)
unnamed: J8.4, U4.6 (I3)
unnamed: J8.5, U4.5 (I4)
unnamed: J8.6, U4.4 (I5)
unnamed: J8.7, U4.3 (I6)
unnamed: J8.8, U4.2 (I7)
unnamed: J9.1, U4.23 (I8)
unnamed: J9.2, U4.22 (I9)
unnamed: J9.3, U4.21 (I10)
unnamed: J9.4, U4.20 (I11)
unnamed: J9.5, U4.19 (I12)
unnamed: J9.6, U4.18 (I13)
unnamed: J9.7, U4.17 (I14)
unnamed: J9.8, U4.16 (I15)
unnamed: C5.2, U4.24 (VCC)
RXD: Jd1.1, U2.40 (RXD0); also elsewhere on the board
TXD: Jd1.2, U2.41 (TXD0); also elsewhere on the board

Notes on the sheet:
ALIMENTACION
DRIVER INPUT
ESC PIN
BOTONES
https://www.studiopieters.nl/esp32-pinout/
MULTIPLEXOR CD74HC4067
EN Y BOOT
AGUJEROS
LED
ESP32 MODULE
I2C
PROGRAMADOR

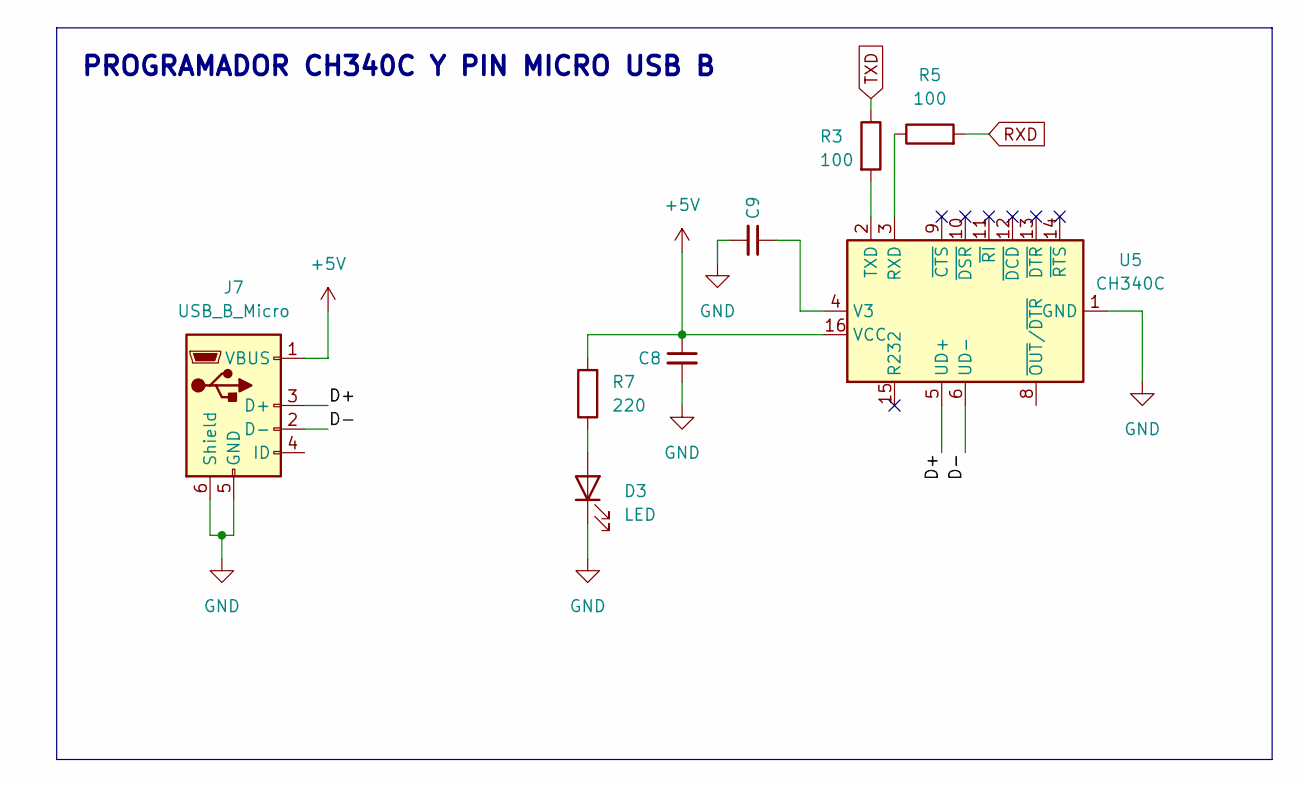
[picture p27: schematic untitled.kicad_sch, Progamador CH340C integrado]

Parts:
C8, C9: C_0805_2012Metric_Pad1.18x1.45mm_HandSolder
D3: LED; LED_0805_2012Metric_Pad1.15x1.40mm_HandSolder
J7: USB_B_Micro; USB_Micro-B_Molex-105017-0001
R3, R5: 100; R_0805_2012Metric_Pad1.20x1.40mm_HandSolder
R7: 220; R_0805_2012Metric_Pad1.20x1.40mm_HandSolder
U5: CH340C; SOIC-16_3.9x9.9mm_P1.27mm

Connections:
+5V: C8.1, J7.1 (VBUS), R7.2, U5.16 (VCC); also elsewhere on the board
/Programador CH340/D+: J7.3 (D+), U5.5 (UD+)
/Programador CH340/D-: J7.2 (D-), U5.6 (UD-)
GND: C8.2, C9.2, D3.1 (K), J7.5 (GND), J7.6 (Shield), U5.1 (GND); also elsewhere on the board
unnamed: D3.2 (A), R7.1
unnamed: R5.1, U5.3 (RXD)
unnamed: R3.2, U5.2 (TXD)
unnamed: C9.1, U5.4 (V3)
RXD: R5.2; also elsewhere on the board
TXD: R3.1; also elsewhere on the board

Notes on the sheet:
PROGRAMADOR CH340C Y PIN MICRO USB B

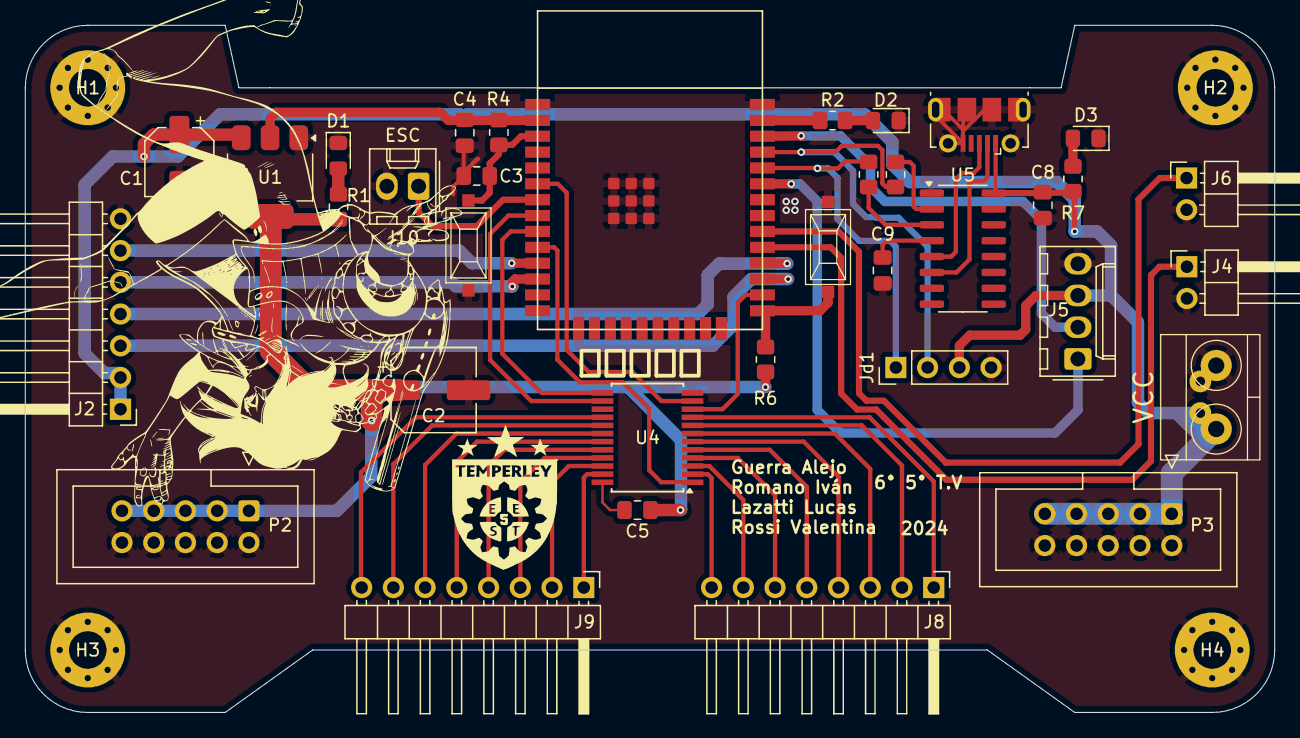
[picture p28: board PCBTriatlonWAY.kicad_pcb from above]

Board: 2 copper layers, 100.0 x 55.0 mm, 39 parts (0 on the bottom side), 47 nets.

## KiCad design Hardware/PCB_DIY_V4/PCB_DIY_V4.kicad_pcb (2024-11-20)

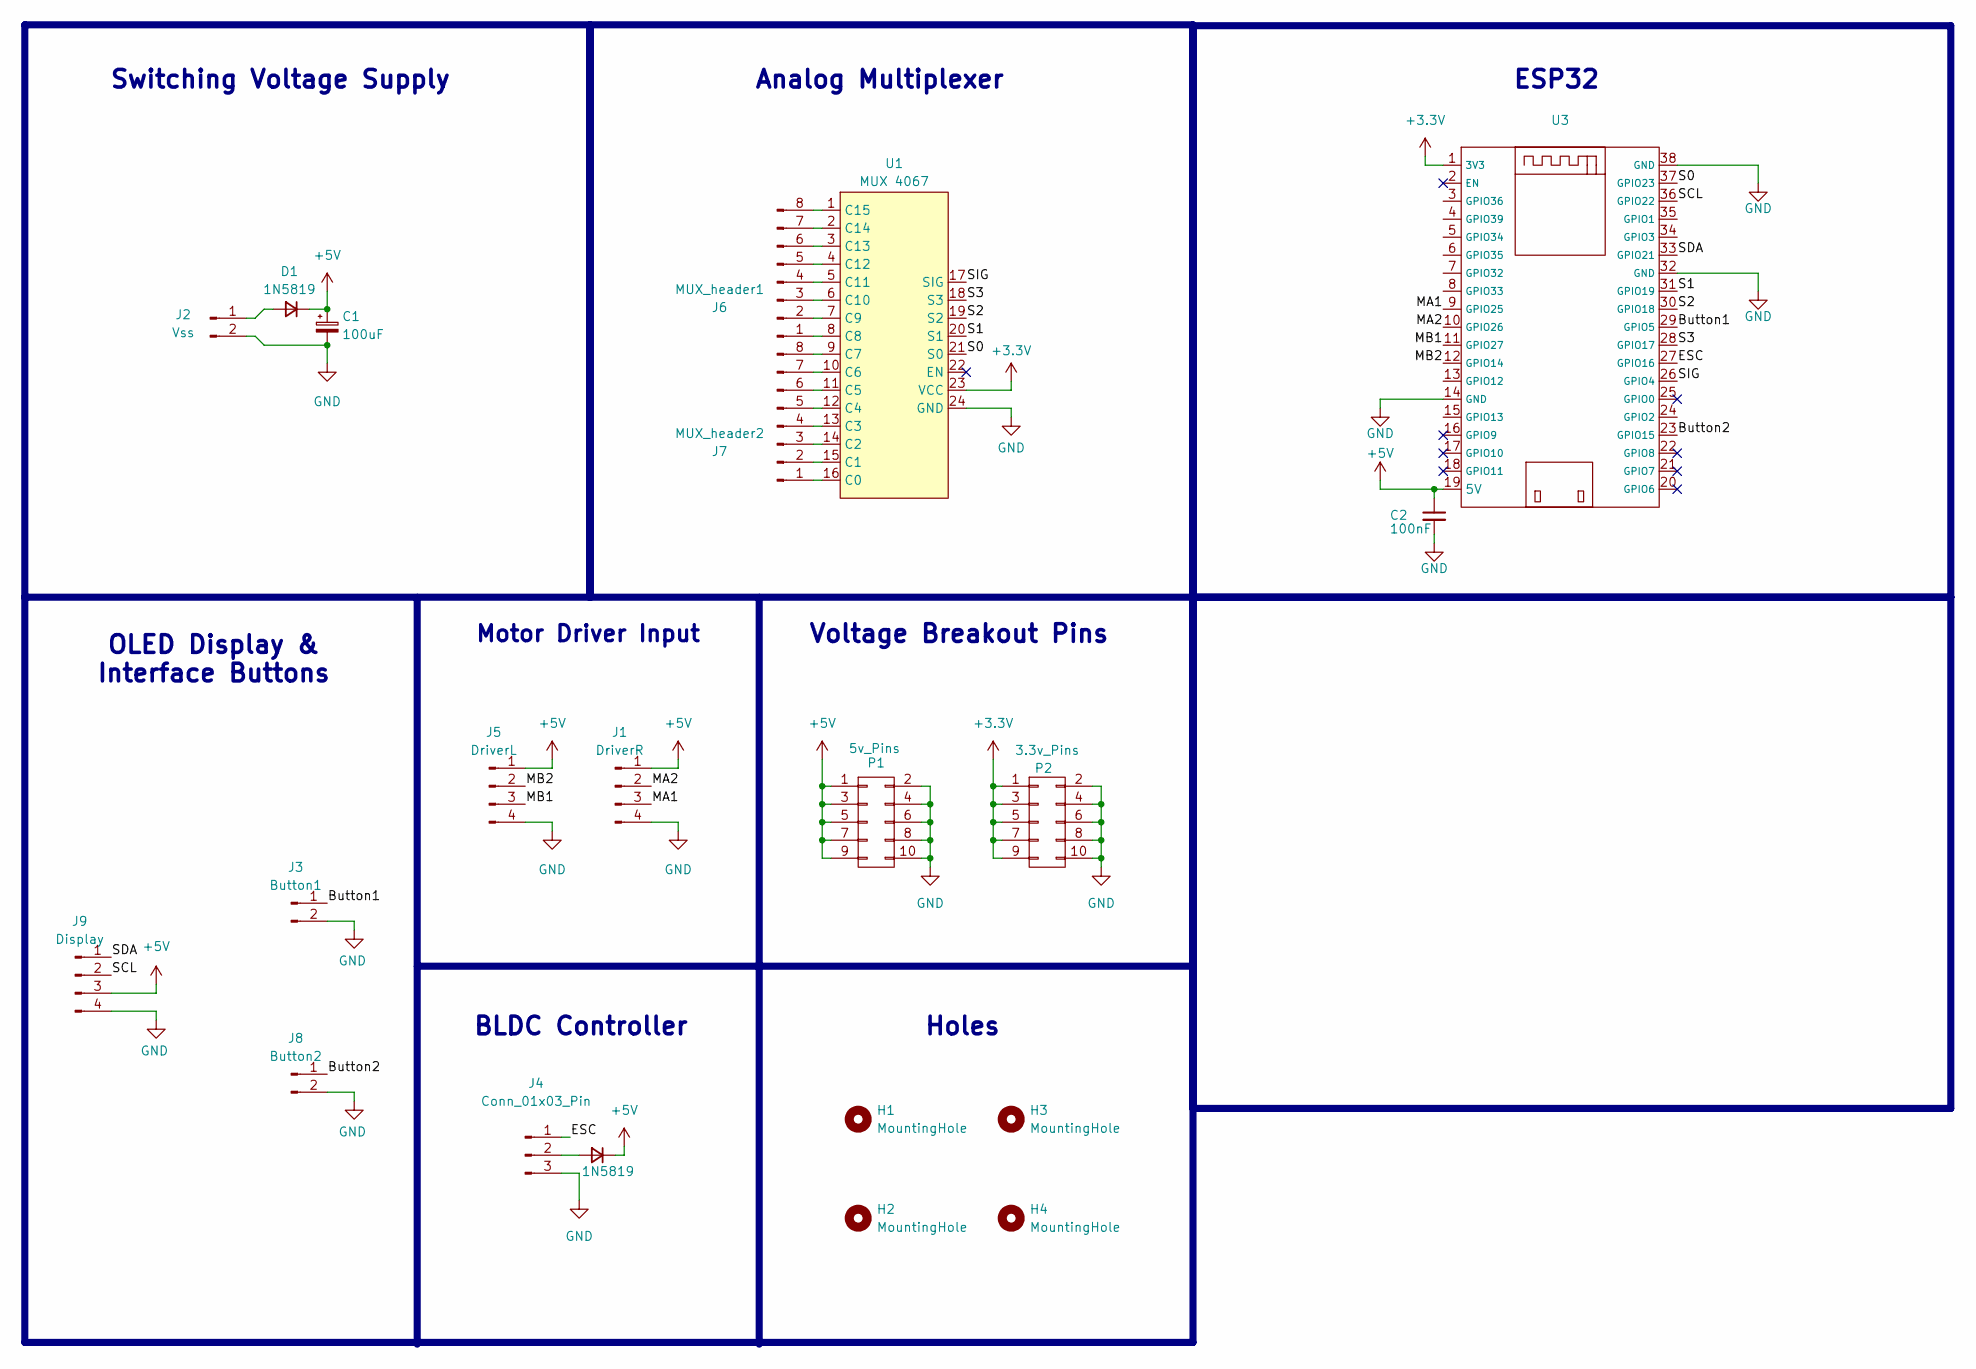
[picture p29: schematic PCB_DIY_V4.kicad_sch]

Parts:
C1: 100uF; CP_Elec_5x4.5
C2: 100nF; C_0805_2012Metric_Pad1.18x1.45mm_HandSolder
D1, D2: 1N5819; D_SMA
H1, H2, H3, H4: MountingHole; MountingHole_3.2mm_M3_DIN965
J1: DriverR; PinHeader_1x04_P2.54mm_Horizontal
J2: Vss; PinHeader_1x02_P2.54mm_Horizontal
J3: Button1; PinHeader_1x02_P2.54mm_Horizontal
J4: Conn_01x03_Pin; Molex_KK-254_AE-6410-03A_1x03_P2.54mm_Vertical
J5: DriverL; PinHeader_1x04_P2.54mm_Horizontal
J6: MUX_header1; PinHeader_1x08_P2.54mm_Horizontal
J7: MUX_header2; PinHeader_1x08_P2.54mm_Horizontal
J8: Button2; PinHeader_1x02_P2.54mm_Horizontal
J9: Display; PinHeader_1x04_P2.54mm_Horizontal
P1: 5v_Pins; IDC-Header_2x05_P2.54mm_Vertical
P2: 3.3v_Pins; IDC-Header_2x05_P2.54mm_Vertical
U1: MUX 4067; HP4067_module
U3: Nodemcu_ESP32S_38pin

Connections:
+3.3V: P2.1, P2.3, P2.5, P2.7, P2.9, U1.23 (VCC), U3.1 (3V3)
+5V: C1.1, C2.1, D1.1 (K), D2.1 (K), J1.1, J5.1, J9.3, P1.1, P1.3, P1.5, P1.7, P1.9, U3.19 (5V)
/Button1: J3.1, U3.29 (GPIO5)
/Button2: J8.1, U3.23 (GPIO15)
/ESC: J4.1, U3.27 (GPIO16)
/MA1: J1.3, U3.9 (GPIO25)
/MA2: J1.2, U3.10 (GPIO26)
/MB1: J5.3, U3.11 (GPIO27)
/MB2: J5.2, U3.12 (GPIO14)
/S0: U1.21 (S0), U3.37 (GPIO23)
/S1: U1.20 (S1), U3.31 (GPIO19)
/S2: U1.19 (S2), U3.30 (GPIO18)
/S3: U1.18 (S3), U3.28 (GPIO17)
/SCL: J9.2, U3.36 (GPIO22)
/SDA: J9.1, U3.33 (GPIO21)
/SIG: U1.17 (SIG), U3.26 (GPIO4)
GND: C1.2, C2.2, J1.4, J2.2, J3.2, J4.3, J5.4, J8.2, J9.4, P1.2, P1.4, P1.6, P1.8, P1.10, P2.2, P2.4, P2.6, P2.8, P2.10, U1.24 (GND), U3.14 (GND), U3.32 (GND), U3.38 (GND)
unnamed: D1.2 (A), J2.1
unnamed: D2.2 (A), J4.2
unnamed: J6.1, U1.8 (C8)
unnamed: J6.2, U1.7 (C9)
unnamed: J6.3, U1.6 (C10)
unnamed: J6.4, U1.5 (C11)
unnamed: J6.5, U1.4 (C12)
unnamed: J6.6, U1.3 (C13)
unnamed: J6.7, U1.2 (C14)
unnamed: J6.8, U1.1 (C15)
unnamed: J7.1, U1.16 (C0)
unnamed: J7.2, U1.15 (C1)
unnamed: J7.3, U1.14 (C2)
unnamed: J7.4, U1.13 (C3)
unnamed: J7.5, U1.12 (C4)
unnamed: J7.6, U1.11 (C5)
unnamed: J7.7, U1.10 (C6)
unnamed: J7.8, U1.9 (C7)

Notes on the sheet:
Analog Multiplexer
Switching Voltage Supply
Holes
BLDC Controller
Voltage Breakout Pins
OLED Display & Interface Buttons
Motor Driver Input
ESP32


Board: 2 copper layers, 100.0 x 55.0 mm, 21 parts (0 on the bottom side), 35 nets.

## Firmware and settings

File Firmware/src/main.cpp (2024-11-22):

#include <Adafruit_GFX.h>
#include <U8g2_for_Adafruit_GFX.h>
#include <CD74HC4067.h>
#include <Bluepad32.h>
#include <multiplexedQTR.h>
#include <bitmaps_triatlon.h>
#include <progress_bars.h>
#include <motor.h>
#include <Bluepad32.h>

bool ctlConnected = false;

bool dataUpdated;

ControllerPtr myControllers[BP32_MAX_GAMEPADS];

#define PIN_MR1 16
#define PIN_MR2 17
#define PIN_ML1 27
#define PIN_ML2 26

#define CHANNEL_MR1 0
#define CHANNEL_MR2 1
#define CHANNEL_ML1 2
#define CHANNEL_ML2 3

#define PWM_FREQUENCY 1000
#define PWM_RESOLUTION 8

bool debug = true;

MotorPair motors(PIN_MR1, PIN_MR2, CHANNEL_MR1, CHANNEL_MR2, PIN_ML1, PIN_ML2,
                 CHANNEL_ML1, CHANNEL_ML2, PWM_FREQUENCY, PWM_RESOLUTION);

Motor motorRight(26, 27, 0, 1, 1000, 8);
Motor motorLeft(16, 17, 2, 3, 1000, 8);

#define SCREEN_WIDTH 128
#define SCREEN_HEIGHT 64
#define OLED_RESET -1
#define SCREEN_ADDRESS 0x3C

#define PIN_SELECT 18
#define PIN_DOWN 5

#define SPRINTER_SCREEN_MARGIN_X 35
#define SPRINTER_SCREEN_MARGIN_Y 0
#define SPRINTER_SCREEN_WIDTH 60
#define SPRINTER_SCREEN_HEIGHT 64

#define CLEANER_SCREEN_MARGIN_X 0
#define CLEANER_SCREEN_MARGIN_Y 0
#define CLEANER_SCREEN_WIDTH 128
#define CLEANER_SCREEN_HEIGHT 64

#define SUMO_SCREEN_MARGIN_X 0
#define SUMO_SCREEN_MARGIN_Y 0
#define SUMO_SCREEN_WIDTH 128
#define SUMO_SCREEN_HEIGHT 64

#define FLAG_SCREEN_MARGIN_X 0
#define FLAG_SCREEN_MARGIN_Y 0
#define FLAG_SCREEN_WIDTH 128
#define FLAG_SCREEN_HEIGHT 64

#define SELECTED_BACKROUND_MARGIN_X 0
#define SELECTED_BACKROUND_MARGIN_Y 22
#define SELECTED_BACKROUND_WIDTH 128
#define SELECTED_BACKROUND_HEIGHT 20

#define ALITA_BITMAP_MARGIN_X 0
#define ALITA_BITMAP_MARGIN_Y 0
#define ALITA_BITMAP_WIDTH 128
#define ALITA_BITMAP_HEIGHT 64

#define ICON_SCREEN_MARGIN_X 4
#define ICON_SCREEN_WIDTH 16
#define ICON_SCREEN_HEIGHT 16

#define PREVIOUS_ICON_SCREEN_MARGIN_Y 2
#define SELECTED_ICON_SCREEN_MARGIN_Y 24
#define NEXT_ICON_SCREEN_MARGIN_Y 46

#define FIRST_SAFETY_TIMEOUT 3000
#define SECOND_SAFETY_TIMEOUT 2000

#define NUM_MODALITIES 3
#define MAX_ITEM_LENGTH 20

Adafruit_SH1106 display(OLED_RESET);
U8G2_FOR_ADAFRUIT_GFX u8g2_for_adafruit_gfx;

ProgressBar displayPB(display);

void DisplayMenu()
{
  if (current_screen == selection)
  {
    display.clearDisplay();

    u8g2_for_adafruit_gfx.setFontMode(1);
    u8g2_for_adafruit_gfx.setFontDirection(0);
    u8g2_for_adafruit_gfx.setForegroundColor(WHITE);
    u8g2_for_adafruit_gfx.setFont(u8g2_font_7x14_mf);
    u8g2_for_adafruit_gfx.setCursor(25, 15);
    u8g2_for_adafruit_gfx.print(F(menu_items[previous]));

    u8g2_for_adafruit_gfx.setFontMode(1);
    u8g2_for_adafruit_gfx.setFontDirection(0);
    u8g2_for_adafruit_gfx.setForegroundColor(WHITE);
    u8g2_for_adafruit_gfx.setFont(u8g2_font_7x14B_mf);
    u8g2_for_adafruit_gfx.setCursor(30, 37);
    u8g2_for_adafruit_gfx.print(F(menu_items[selected]));

    u8g2_for_adafruit_gfx.setFontMode(1);
    u8g2_for_adafruit_gfx.setFontDirection(0);
    u8g2_for_adafruit_gfx.setForegroundColor(WHITE);
    u8g2_for_adafruit_gfx.setFont(u8g2_font_7x14_mf);
    u8g2_for_adafruit_gfx.setCursor(25, 59);
    u8g2_for_adafruit_gfx.print(F(menu_items[next]));

    display.drawXBitmap(SELECTED_BACKROUND_MARGIN_X, SELECTED_BACKROUND_MARGIN_Y, epd_bitmap_selected_background, SELECTED_BACKROUND_WIDTH, SELECTED_BACKROUND_HEIGHT, WHITE);

    display.drawXBitmap(ICON_SCREEN_MARGIN_X, PREVIOUS_ICON_SCREEN_MARGIN_Y, bitmap_icons[previous], ICON_SCREEN_WIDTH, ICON_SCREEN_HEIGHT, WHITE);
    display.drawXBitmap(ICON_SCREEN_MARGIN_X, SELECTED_ICON_SCREEN_MARGIN_Y, bitmap_icons[selected], ICON_SCREEN_WIDTH, ICON_SCREEN_HEIGHT, WHITE);
    display.drawXBitmap(ICON_SCREEN_MARGIN_X, NEXT_ICON_SCREEN_MARGIN_Y, bitmap_icons[next], ICON_SCREEN_WIDTH, ICON_SCREEN_HEIGHT, WHITE);

    display.display();
  }
  else if (current_screen == modality && selected == sprinter)
  {
    displayPB.load(SPRINTER_SCREEN_MARGIN_X, SPRINTER_SCREEN_MARGIN_Y, SPRINTER_SCREEN_WIDTH, SPRINTER_SCREEN_HEIGHT, FIRST_SAFETY_TIMEOUT);
    displayPB.unload(SPRINTER_SCREEN_MARGIN_X, SPRINTER_SCREEN_MARGIN_Y, SPRINTER_SCREEN_WIDTH, SPRINTER_SCREEN_HEIGHT, SECOND_SAFETY_TIMEOUT);

    current_screen = flags;
  }
  else if (current_screen == modality && selected == areaCleaner)
  {
    displayPB.load(CLEANER_SCREEN_MARGIN_X, CLEANER_SCREEN_MARGIN_Y, CLEANER_SCREEN_WIDTH, CLEANER_SCREEN_HEIGHT, FIRST_SAFETY_TIMEOUT);
    displayPB.unload(CLEANER_SCREEN_MARGIN_X, CLEANER_SCREEN_MARGIN_Y, CLEANER_SCREEN_WIDTH, CLEANER_SCREEN_HEIGHT, SECOND_SAFETY_TIMEOUT);

    current_screen = flags;
  }
  else if (current_screen == flags)
  {
    display.clearDisplay();
    display.drawXBitmap(FLAG_SCREEN_MARGIN_X, FLAG_SCREEN_MARGIN_Y, epd_bitmap_flag, FLAG_SCREEN_WIDTH, FLAG_SCREEN_HEIGHT, WHITE);
    display.display();
  }
  else if (current_screen == modality && selected == sumo)
  {
    if (!ctlConnected)
    {
      display.clearDisplay();
      display.drawXBitmap(SUMO_SCREEN_MARGIN_X, SUMO_SCREEN_MARGIN_Y, bitmap_screens[selected], SUMO_SCREEN_WIDTH, SUMO_SCREEN_HEIGHT, WHITE);
      display.display();

      delay(250);

      display.clearDisplay();
      display.display();

      delay(250);
    }
    else
    {
      display.clearDisplay();
      display.drawXBitmap(SUMO_SCREEN_MARGIN_X, SUMO_SCREEN_MARGIN_Y, bitmap_screens[selected], SUMO_SCREEN_WIDTH, SUMO_SCREEN_HEIGHT, WHITE);
      display.display();
    }
  }
  else if (current_screen == modality && selected == sprinter)
  {
    display.clearDisplay();
    display.drawXBitmap(0, 0, bitmap_screens[selected], 128, 64, WHITE);
    display.display();
  }

  UpdateScreenStatus();

  if (current_screen == selection)
  {
    motors.StayStill();

    motorRight.StayStill();
    motorLeft.StayStill();

    BP32.enableNewBluetoothConnections(false);
  }
}

multiplexedQTR qtr;

const uint8_t SensorCount = 8;
uint16_t sensorValues[SensorCount];

int position;

int getPosition()
{
  position = qtr.readLineWhite(sensorValues);
  return position;
}

void StartSprinterCalibration()
{
  qtr.setTypeAnalog();
  qtr.setSensorPins((const uint8_t[]){0, 1, 2, 3, 4, 5, 6, 7}, SensorCount);

  delay(500);

  display.clearDisplay();
  display.drawXBitmap(0, 0, bitmap_calibration, 124, 64, WHITE);
  display.display();

  for (uint16_t i = 0; i < 350; i++)
  {
    qtr.calibrate();
  }

  current_screen = modality;
}

int setPoint = 1750;

int proportional;
int derivative;
int integral;
int lastError;

int maxSpeed = 180;
int minSpeed = 140;
int speed = 160;

float kp = 0.013;
float ki = 0;
float kd = 0;
float pid;
float pidRight;
float pidLeft;

void StartSprinterModality()
{
  position = getPosition();

  proportional = position - setPoint;
  derivative = proportional - lastError;

  pid = (proportional * kp) + (derivative * kd);

  lastError = proportional;

  pidRight = speed + pid;
  pidLeft = speed - pid;

  if (pidRight > maxSpeed)
  {
    pidRight = maxSpeed;
  }
  if (pidLeft > maxSpeed)
  {
    pidLeft = maxSpeed;
  }

  if (pidRight <= minSpeed && pidLeft > minSpeed)
  {
    motors.TurnRight(minSpeed + (minSpeed - pidRight), pidLeft);
  }
  else if (pidLeft <= minSpeed && pidRight > minSpeed)
  {
    motors.TurnLeft(pidRight, minSpeed + (minSpeed - pidLeft));
  }
  else
  {
    motors.MoveForward(pidRight, pidLeft);
  }
}

#define QRE_BLACK 3900
#define SHARP_ATTACK 1000
#define SET_OUT_BACKWARDS_TIME 250

int LOW_SPEED = 85;
int MID_SPEED = 95;
int FULL_SPEED = 110;

bool offRoad;

int sharp_left;
int sharp_right;
int sharp_front_right;
int sharp_front;
int sharp_front_left;
int qre_back;
int qre_left;
int qre_right;

int signal_input;

#define PIN_S0 4
#define PIN_S1 25
#define PIN_S2 33
#define PIN_S3 32
#define PIN_SIG 34

CD74HC4067 my_mux(PIN_S0, PIN_S1, PIN_S2, PIN_S3);

void ReadCleanerSensors()
{

  for (int x = 8; x < 15; x++)
  {

    my_mux.channel(x);

    signal_input = analogRead(PIN_SIG);

    switch (x)
    {

    case 8:
    {
      qre_left = signal_input;
      break;
    }
    case 9:
    {
      qre_back = signal_input;
      break;
    }
    case 10:
    {
      qre_right = signal_input;
      break;
    }
    case 11:
    {
      sharp_right = signal_input;
      break;
    }
    case 12:
    {
      sharp_front_right = signal_input;
      break;
    }
    case 13:
    {
      sharp_front = signal_input;
      break;
    }
    case 14:
    {
      sharp_front_left = signal_input;
      break;
    }
    case 15:
    {
      sharp_left = signal_input;
      break;
    }
    }
  }
}

void CheckOffRoad()
{
  ReadCleanerSensors();

  if (qre_left > QRE_BLACK || qre_right > QRE_BLACK || qre_back > QRE_BLACK)
  {
    offRoad = true;
  }
  else
  {
    offRoad = false;
  }
}

bool out_lastMovment;
#define BarzolaTurn 1000
#define SafetyStop 700

void Out()
{
  ReadCleanerSensors();

  unsigned long CurrentTime_OUT;

  if (qre_left > QRE_BLACK || qre_right > QRE_BLACK)
  {
    CurrentTime_OUT = millis();

    while (millis() < CurrentTime_OUT + SET_OUT_BACKWARDS_TIME)
    {
      ReadCleanerSensors();
      CheckOffRoad();
      motors.MoveBackwards(FULL_SPEED, FULL_SPEED);
      if (qre_back > QRE_BLACK)
      {
        break;
      }
      delay(10);
    }

    while (millis() < CurrentTime_OUT + BarzolaTurn)
    {
      ReadCleanerSensors();
      CheckOffRoad();
      motors.TurnRight(LOW_SPEED, LOW_SPEED);
      if (sharp_front_left > SHARP_ATTACK || sharp_front > SHARP_ATTACK || sharp_front_right > SHARP_ATTACK)
      {
        break;
      }
      if (offRoad)
      {
        break;
      }
      delay(10);
    }

    out_lastMovment = true;
    CheckOffRoad();
  }

  if (qre_back > QRE_BLACK)
  {
    CurrentTime_OUT = millis();

    if (out_lastMovment)
    {
      while (millis() < CurrentTime_OUT + 200)
      {
        ReadCleanerSensors();
        CheckOffRoad();
        motors.MoveForward(MID_SPEED, MID_SPEED);
        delay(10);
      }
    }
    else if (!out_lastMovment)
    {
      while (millis() < CurrentTime_OUT + SET_OUT_BACKWARDS_TIME)
      {
        ReadCleanerSensors();
        CheckOffRoad();
        motors.MoveBackwards(FULL_SPEED, FULL_SPEED);
        delay(10);
      }

      while (millis() < CurrentTime_OUT + SafetyStop)
      {
        ReadCleanerSensors();
        CheckOffRoad();
        motors.Brake();
        delay(10);
      }
    }
  }
}

bool state_found_left;
bool state_found_right;
bool object_back;
long time_found_left;
long time_found_right;

void OutObjectBack()
{
  ReadCleanerSensors();
  CheckOffRoad();
  long CurrentTime_ObjectBack;
  int total_found_left;
  int total_found_right;

  if (state_found_left)
  {
    total_found_left = millis() - (time_found_left + SET_OUT_BACKWARDS_TIME);
  }
  if (state_found_right)
  {
    total_found_right = millis() - (time_found_right + SET_OUT_BACKWARDS_TIME);
  }

  if (state_found_left && !state_found_right)
  {
    while (millis() < CurrentTime_ObjectBack + total_found_left)
    {
      motors.MoveBackwards(MID_SPEED, MID_SPEED);
      delay(10);
    }
  }
  else if (!state_found_left && state_found_right)
  {
    while (millis() < CurrentTime_ObjectBack + total_found_right)
    {
      motors.MoveBackwards(MID_SPEED, MID_SPEED);
      delay(10);
    }
  }
  else if (state_found_left && state_found_right)
  {
    if (total_found_left < total_found_right)
    {
      while (millis() < CurrentTime_ObjectBack + total_found_left)
      {
        motors.MoveBackwards(MID_SPEED, MID_SPEED);
        delay(10);
      }
    }
    else if (total_found_left > total_found_right)
    {
      while (millis() < CurrentTime_ObjectBack + total_found_right)
      {
        motors.MoveBackwards(MID_SPEED, MID_SPEED);
        delay(10);
      }
    }
  }

  object_back = false;
  state_found_left = false;
  state_found_right = false;
  total_found_left = 0;
  total_found_right = 0;
  time_found_left = 0;
  time_found_right = 0;
}

void SearchAllTheTrack()
{
  ReadCleanerSensors();
  CheckOffRoad();
  long CurrentTime_SearchAllTheTrack;

  CurrentTime_SearchAllTheTrack = millis();

  if (!offRoad)
  {
    motors.MoveForward(MID_SPEED, MID_SPEED);
  }
  else
  {
    motors.TurnRight(LOW_SPEED, MID_SPEED);
  }
}

void SearchObject()
{

  ReadCleanerSensors();
  CheckOffRoad();

  long CurrentTime_SearchObject = millis();

  for (int i = 0; i < 18; i++)
  {
    long CurrentTime_Brake = millis() + 200;
    long CurrentTime_TurnRight = millis() + 100;

    while (millis() < CurrentTime_TurnRight)
    {
      motors.TurnRight(MID_SPEED, MID_SPEED);
      ReadCleanerSensors();
      if (sharp_front_left > SHARP_ATTACK || sharp_front > SHARP_ATTACK || sharp_front_right > SHARP_ATTACK)
      {
        break;
      }
      if (offRoad)
      {
        break;
      }
    }
    while (millis() < CurrentTime_Brake)
    {
      motors.Brake();
      ReadCleanerSensors();
      if (sharp_front_left > SHARP_ATTACK || sharp_front > SHARP_ATTACK || sharp_front_right > SHARP_ATTACK)
      {
        break;
      }
      if (sharp_right > SHARP_ATTACK)
      {
        break;
      }
      if (offRoad)
      {
        break;
      }
    }

    if (sharp_front_left > SHARP_ATTACK || sharp_front > SHARP_ATTACK || sharp_front_right > SHARP_ATTACK)
    {
      break;
    }
    if (offRoad)
    {
      break;
    }

    i = i + 1;
  }

  while (millis() < CurrentTime_SearchObject + 2000)
  {
    ReadCleanerSensors();
    CheckOffRoad();
    motors.MoveForward(MID_SPEED, MID_SPEED);

    if (sharp_front_left > SHARP_ATTACK || sharp_front > SHARP_ATTACK || sharp_front_right > SHARP_ATTACK)
    {
      break;
    }

    if (offRoad)
    {
      break;
    }
    delay(10);
  }
}

void StartAreaCleanerSection()
{
  ReadCleanerSensors();
  CheckOffRoad();

  if (offRoad)
  {
    Out();
  }

  else
  {
    if (sharp_front_left > SHARP_ATTACK || sharp_front > SHARP_ATTACK || sharp_front_right > SHARP_ATTACK)
    {

      out_lastMovment = false;

      if (sharp_front_left > sharp_front)
      {
        motors.TurnLeft(MID_SPEED, 0);
      }
      else if (sharp_front_right > sharp_front)
      {
        motors.TurnRight(0, MID_SPEED);
      }
      else
      {
        ReadCleanerSensors();
        CheckOffRoad();

        motors.MoveForward(FULL_SPEED, FULL_SPEED);
      }
    }

    else
    {
      SearchObject();
    }
  }
}

int axisXValue;
int throttleValue;
int brakeValue;

int throttlePWM;
int brakePWM;
int leftPWM;
int rightPWM;

void onConnectedController(ControllerPtr ctl)
{

  bool foundEmptySlot = false;

  ctlConnected = true;

  if (myControllers[0] == nullptr)
  {
    Serial.printf("CALLBACK: Controller is connected, index=%d\n");
    ControllerProperties properties = ctl->getProperties();
    Serial.printf("Controller model: %s, VID=0x%04x, PID=0x%04x\n", ctl->getModelName().c_str(), properties.vendor_id, properties.product_id);
    myControllers[0] = ctl;
    foundEmptySlot = true;
  }

  if (!foundEmptySlot)
  {
    Serial.println("CALLBACK: Controller connected, but could not found empty slot");
  }
}

void onDisconnectedController(ControllerPtr ctl)
{
  bool foundController = false;

  ctlConnected = false;

  if (myControllers[0] == ctl)
  {
    Serial.printf("CALLBACK: Controller disconnected from index=%d\n");
    myControllers[0] = nullptr;
    foundController = true;
  }

  if (!foundController)
  {
    Serial.println("CALLBACK: Controller disconnected, but not found in myControllers");
  }
}

void processGamepad(ControllerPtr ctl)
{
  bool brakeRight;
  bool brakeLeft;

  int yAxisValueR = ctl->axisRY();
  int yAxisValueL = ctl->axisY();

  int RBValue = ctl->throttle();
  int LBValue = ctl->brake();

  int rightWheelSpeedF = map(yAxisValueR, 0, -511, 0, 255);
  int rightWheelSpeedB = map(yAxisValueR, 0, 512, 0, 255);

  int leftWheelSpeedF = map(yAxisValueL, 0, -511, 0, 255);
  int leftWheelSpeedB = map(yAxisValueL, 0, 512, 0, 255);

  int turnRightSpeed = map(RBValue, 0, 1023, 0, 255);
  int turnLeftSpeed = map(LBValue, 0, 1023, 0, 255);

  if (ctl->r1())
  {
    brakeRight = true;
  }
  else
  {
    brakeRight = false;
  }
  if (ctl->l1())
  {
    brakeLeft = true;
  }
  else
  {
    brakeLeft = false;
  }

  if (!brakeRight)
  {
    if (yAxisValueR < -70)
    {
      motorRight.MoveForward(rightWheelSpeedF);
    }
    else if (yAxisValueR > 70)
    {
      motorRight.MoveBackwards(rightWheelSpeedB);
    }
    else
    {
      motorRight.StayStill();
    }
  }
  else
  {
    motorRight.StayStill();
  }

  if (!brakeLeft)
  {
    if (yAxisValueL < -70)
    {
      motorLeft.MoveForward(leftWheelSpeedF);
    }
    else if (yAxisValueL > 70)
    {
      motorLeft.MoveBackwards(leftWheelSpeedB);
    }
    else
    {
      motorLeft.StayStill();
    }
  }
  else
  {
    motorLeft.StayStill();
  }

  if (RBValue > 150)
  {
    motorRight.MoveBackwards(turnRightSpeed);
    motorLeft.MoveForward(turnRightSpeed);
  }

  if (LBValue > 150)
  {
    motorRight.MoveForward(turnLeftSpeed);
    motorLeft.MoveBackwards(turnLeftSpeed);
  }
}

void processControllers()
{
  for (auto myController : myControllers)
  {
    if (myController && myController->isConnected() && myController->hasData())
    {
      processGamepad(myController);
    }
  }
}

void StartSumoModality()
{
  BP32.enableNewBluetoothConnections(true);

  dataUpdated = BP32.update();

  if (dataUpdated)
  {
    processControllers();
  }
}

void StartModalityTriggers()
{
  if (current_screen == flags && selected == areaCleaner)
  {
    StartAreaCleanerSection();
  }
  else if (current_screen == modality && selected == sumo)
  {
    StartSumoModality();
  }
  else if (current_screen == calibration)
  {
    StartSprinterCalibration();
  }
  else if (current_screen == flags && selected == sprinter)
  {
    StartSprinterModality();
  }
}

#define PIN_LED 23

void setup()
{
  display.begin(SH1106_SWITCHCAPVCC, SCREEN_ADDRESS);

  u8g2_for_adafruit_gfx.begin(display);

  pinMode(PIN_LED, OUTPUT);
  digitalWrite(PIN_LED, HIGH);

  BP32.setup(&onConnectedController, &onDisconnectedController);

  pinMode(PIN_SELECT, INPUT_PULLUP);
  pinMode(PIN_DOWN, INPUT_PULLUP);

  display.clearDisplay();
  display.drawBitmap(ALITA_BITMAP_MARGIN_X, ALITA_BITMAP_MARGIN_Y, bitmap_alita, ALITA_BITMAP_WIDTH, ALITA_BITMAP_HEIGHT, WHITE);
  display.display();

  delay(3000);
}

void loop()
{
  DisplayMenu();
  StartModalityTriggers();
}

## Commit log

2024-04-11 Piezas del robot
    cosas pa imprimir
    [SUMOTRIATLONMAIN.stl, SoporteCentral.stl, SoporteDerecho.stl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]
2024-04-13 Hardware del robot
    Placas Agregadas
    - Qre1113 x8 module
    - Driver TB67H459FNG x2
    //Falta Main board //
    [DriverMotoresx2TB67H450FNG.kicad_pcb, DriverMotoresx2TB67H450FNG.kicad_sch, DriverMotoresx2TB67H450FNG.step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]
2024-04-13 Hardware 3D STL's del robot
    Chasis, brackets, etc del robot
    - Piezas a imprimir
    [Chasis principal.stl, SoporteCentral.stl, SoporteDerecho.stl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]
2024-04-13 Delete SUMOTRIATLONMAIN.stl
    xd
    [SUMOTRIATLONMAIN.stl]
2024-04-13 Delete SoporteCentral.stl
    Agregado al Hardware3D
    [SoporteCentral.stl]
2024-04-13 Delete SoporteDerecho.stl
    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
    [SoporteDerecho.stl]
2024-04-13 Delete SoporteIzquierdo.stl
    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
    [SoporteIzquierdo.stl]
2024-04-15 Delete Hardware/TriatlónPlanB.kicad_pcb
    Añadido en TriatlonB
    [TriatlónPlanB.kicad_pcb]
2024-04-15 Delete Hardware/TriatlónPlanB.kicad_prl
    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
2024-04-15 Delete Hardware/TriatlónPlanB.kicad_pro
    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
2024-04-15 Delete Hardware/TriatlónPlanB.kicad_sch
    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
    [TriatlónPlanB.kicad_sch]
2024-04-23 Molde de Cubierta
    Molde de rueda para 50mm, total 60mm.
    [MoldeRueda60MM.stl]
2024-06-04 Cambiando la carpeta Hardware por Firmware.
2024-06-04 Probando que se ya se usar git.
2024-06-05 Deshaciendo prueba de jere
2024-06-05 Cambios de la barra de carga
2024-06-10 Probando a commitear desde un archivo de platformio
2024-07-04 Dejando lista la version estable
2024-07-04 Subiendo el main.cpp de romano
2024-07-29 Agregando codigo de ivan
2024-08-18 Eliminación de sobrantes
2024-08-18 Actualizando a la última versión de desarrollo
2024-09-08 Placa Main Para fabricar
    Placa con ESP32, Multiplexor CD74HC4067SM, Programador CH340C
    [PCBTriatlonWAY.kicad_pcb, PCBTriatlonWAY.kicad_sch, untitled.kicad_sch]
2024-09-16 Preparando rama individual de despeja area
    [Chasis principal.stl, DriverMotoresx2TB67H450FNG.kicad_pcb, DriverMotoresx2TB67H450FNG.kicad_sch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]
2024-09-16 Actualizando librería motors
2024-09-16 Cambiando librería de motores
2024-09-19 Gerber de la pcb
    Tiene los pines de rx y tx con header, y las conexiones del ch340c switcheadas ( TX a RX - RX a TX)
2024-09-19 Creando rama de testing
    [Chasis principal.stl, DriverMotoresx2TB67H450FNG.kicad_pcb, DriverMotoresx2TB67H450FNG.kicad_sch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]
2024-09-19 Placa Triatlon
    [PCBTriatlonWAY.kicad_pcb, PCBTriatlonWAY.kicad_sch, untitled.kicad_sch]
2024-09-19 Other, Placa Minisumo328p
    xd pq subia esto aca
    [mini sumo 328P.kicad_pcb, mini sumo 328P.kicad_sch, untitled.kicad_sch]
2024-10-10 Orden de directorios y proyecto de KiCad añadido
    [Alita_PCB_V4.kicad_pcb, Alita_PCB_V4.kicad_sch, Chasis principal.stl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]
2024-10-10 Schematid updated
    [Alita_PCB_V4.kicad_sch]
2024-10-10 Placa de drivers añadida
    [Parallel_TB67_driver.kicad_pcb, Parallel_TB67_driver.kicad_sch]
2024-10-11 Avances en esquematico
    [Alita_PCB_V4.kicad_pcb, Alita_PCB_V4.kicad_sch]
2024-10-11 Asignacion de huellas
    [Alita_PCB_V4.kicad_pcb, Alita_PCB_V4.kicad_sch]
2024-10-12 Primer posicionamiento de componentes en PCB
    [Alita_PCB_V4.kicad_pcb, Alita_PCB_V4.kicad_sch]
2024-10-12 Modificacion de footprint y posicionamiento
    [Alita_PCB_V4.kicad_pcb, Alita_PCB_V4.kicad_sch]
2024-10-13 Segundo posicionamiento de componentes y ruteo parcial
    [Alita_PCB_V4.kicad_pcb, Alita_PCB_V4.kicad_sch]
2024-10-13 Ruteo y PCB completada
    [Alita_PCB_V4.kicad_pcb]
2024-10-13 Primera revisión PCB
    [Alita_PCB_V4.kicad_pcb]
2024-10-14 PCB_V4: Pinout del ESP32 arreglado
    el driver estaba conectado a los pines de input only jeje
    [Alita_PCB_V4.kicad_pcb, Alita_PCB_V4.kicad_sch]
2024-10-14 PCB_V4: conexion a GND de C1 arreglada
    [Alita_PCB_V4.kicad_pcb, Alita_PCB_V4.kicad_sch]
2024-10-17 Añadi el simbolo arreglado al esquematico y PCB
    [Alita_PCB_V4.kicad_pcb, Alita_PCB_V4.kicad_sch]
2024-10-17 Configurando rama para la modalidad Srinter
2024-10-17 Archivos de Chasis y Ruedas V3
    Hola si leen esto, en algún momento del día díganme pez
    [ChasisV3.stl, Rueda60MM Mod.stl, RuedaTitanMolde60MM.stl]
2024-10-19 Arregle la PCB
    Arregle la PCB lol
    [Alita_PCB_V4.kicad_pcb, PCB_DIY_V4.kicad_pcb, PCB_DIY_V4.kicad_sch]
2024-10-22 Cambiando el pinout del multiplexor
2024-10-23 Agragando PCB plan B
    [PCB_DIY_V4.kicad_pcb, PCB_DIY_V4.kicad_sch]
2024-10-23 Acondicionando la PCB nueva
2024-10-23 Adaptando a PCB V2 denuevo
2024-11-20 Making minor changes
    - Deleted useless comments
    - Deleted bluetooth features
    - Fixing indentation and gaps problems
    [main.cpp]
2024-11-20 Making minor changes
    - Split menu features apart from other features
    - Replaced some values with constants
    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
    [main.cpp]
2024-11-22 Fixing incompatibilities and making minor changes
    - Deleted incongruity
    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
    [main.cpp]
